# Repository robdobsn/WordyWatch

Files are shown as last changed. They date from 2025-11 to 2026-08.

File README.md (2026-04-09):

# WordyWatch

A wearable word clock watch that displays time using military time format in words. See [A Wordy Watch](https://robdobson.com/2026/04/a-wordy-watch/) for full build details. Inspired by [QlockTwo](https://www.qlocktwo.com/en-us) word clocks, WordyWatch brings this elegant time display concept to a wrist-worn device. 

## Overview

WordyWatch displays time using illuminated words instead of traditional digits. Instead of showing "11:05", it displays "eleven oh five hours". The watch uses a charlieplexed LED matrix to light up words on a custom PCB, creating a unique and readable time display.

## Military Time Format

The watch displays time in military/24-hour format with 5-minute intervals:

- `00:00` → "zero hundred hours"
- `00:05` → "zero oh five hours"  
- `11:00` → "eleven hundred hours"
- `11:05` → "eleven oh five hours"
- `23:55` → "twenty three fifty five hours"

## Key Features

- **Word-based time display** with charlieplexed LED matrix
- **Military time format** for unambiguous time reading
- **5-minute intervals** for practical readability
- **Compact wearable design** optimized for wrist-worn use
- **Custom PCB** with integrated word layout
- **ESP32-C6 based** firmware for reliable operation

## Project Structure

### 📱 **WordyWatchWebApp/**
React-based web application for designing and testing word clock layouts. This tool allows you to:
- Visualize different word arrangements and grid layouts
- Test military time display with various times
- Customize fonts and spacing
- Export layouts for use in firmware
- Experiment with new word patterns before manufacturing

Built with React 18, TypeScript, Vite, and Tailwind CSS.

See [WordyWatchWebApp/README.md](WordyWatchWebApp/README.md) for detailed usage instructions.

### 🔧 **WordyFW/**
ESP32-C6 firmware for the WordyWatch hardware. Handles:
- Real-time clock management
- LED matrix control via charlieplexing
- Power management for battery operation
- Word selection and timing logic
- User interface and button controls

### 🔌 **PCB/**
Custom PCB designs and tools for the WordyWatch hardware:

#### CharlieplexGenerator/
Python scripts for generating charlieplexed LED matrix layouts in EasyEDA format:
- `generate_charlieplex_sch.py` - Generates schematics for 12×11 LED matrices (132 LEDs)
- Automatic routing and connection generation
- Supports customizable grid spacing and positioning

See [PCB/CharlieplexGenerator/README.md](PCB/CharlieplexGenerator/README.md) for details.

### 🎨 **Design/**
Design files, documentation, and optimization experiments:
- Grid layout optimization attempts
- Word pattern analysis
- Design specifications and requirements
- Visual mockups and concepts

## Technology Stack

- **Hardware**: ESP32-C6, charlieplexed LED matrix (132 LEDs from 12 GPIO lines)
- **Firmware**: C/C++ with ESP-IDF
- **PCB Design**: EasyEDA with custom Python generators
- **Web Tools**: React 18 + TypeScript + Vite
- **LED Components**: XL-1608UWC-04 white LEDs (LCSC C965808)

## Getting Started

### For Web App Development
```bash
cd WordyWatchWebApp
npm install
npm run dev
```

### For PCB Generation
```bash
cd PCB/CharlieplexGenerator
python generate_charlieplex_sch.py SCH_TestCharlieplex1_2025-11-02.json output.json
```

### For Firmware Development
```bash
cd WordyFW
# Follow ESP-IDF build instructions
```

## How Charlieplexing Works

WordyWatch uses charlieplexing to control 132 LEDs with only 12 GPIO pins:
- With N GPIO lines, you can control N×(N-1) LEDs
- Each LED is connected between two different GPIO lines
- Only one LED (or set on the same line pair) lights at a time
- Rapid multiplexing creates the illusion of multiple LEDs being lit simultaneously

## Contributing

1. Fork the repository
2. Create a feature branch (`git checkout -b feature/amazing-feature`)
3. Commit your changes (`git commit -m 'Add amazing feature'`)
4. Push to the branch (`git push origin feature/amazing-feature`)
5. Open a Pull Request

## License

This project is open source and available under the MIT License. See [LICENSE](LICENSE) for details.

Copyright (c) 2025 Rob Dobson

## Acknowledgments

- Inspired by [QlockTwo](https://www.qlocktwo.com/en-us) word clocks
- Built for experimentation with charlieplexing and wearable displays

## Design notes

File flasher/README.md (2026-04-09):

# WordyWatch Web Flasher

A browser-based firmware flasher for the WordyWatch (ESP32-C6) using [ESP Web Tools](https://esphome.github.io/esp-web-tools/) and WebSerial.

## How it works

The flasher is a single static HTML page hosted on GitHub Pages. When a user clicks the install button, the browser connects to the watch over USB-C using the WebSerial API and flashes the firmware directly — no tools or drivers needed.

## Deployed URL

After enabling GitHub Pages, the flasher is available at:

```
https://robdobsn.github.io/WordyWatch/
```

## Build & deployment

The GitHub Actions workflow (`.github/workflows/deploy-flasher.yml`) runs automatically when a new release is published:

1. Builds the firmware inside the `espressif/idf:v5.5.2` Docker container using `idf.py -B build/WordyWatchV11 build`
2. Copies the three flash binaries (bootloader, partition table, application) into the site
3. Generates `manifest.json` with the release version tag
4. Deploys everything to GitHub Pages

The workflow can also be triggered manually from the Actions tab using `workflow_dispatch`.

## GitHub Pages setup

To enable GitHub Pages for this repo:

1. Go to **Settings → Pages** in the GitHub repository
2. Under **Build and deployment → Source**, select **GitHub Actions**

That's all — the workflow handles the rest.

## Flash layout

| Binary | Offset | Description |
|---|---|---|
| `bootloader.bin` | `0x0` | ESP32-C6 second-stage bootloader |
| `partition-table.bin` | `0x8000` | Partition table |
| `WordyWatchV11.bin` | `0x20000` | Application firmware |

## Browser support

WebSerial is required, which is supported in:

- Google Chrome (desktop)
- Microsoft Edge (desktop)

Firefox, Safari, and mobile browsers are **not supported**. The page shows a clear message to users on unsupported browsers.

## Local development

To preview the flasher page locally:

```bash
cd flasher
python3 -m http.server 8000
```

Then open `http://localhost:8000`. Note that WebSerial requires HTTPS in production, but works on `localhost` for testing.

## Files

| File | Purpose |
|---|---|
| `index.html` | Flasher page with ESP Web Tools install button |
| `firmware/manifest.json` | Template manifest (overwritten by CI with actual version) |

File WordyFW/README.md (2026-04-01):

# WordyWatch Functionality Specification

## Overview

WordyWatch is a wrist-worn word clock built on ESP32-C6, displaying the current time as illuminated English words on a 12×11 charlieplexed LED matrix. The watch sleeps between glances and wakes on wrist tilt to show the time for a few seconds before returning to deep sleep.

## Hardware Platform

| Component | Detail |
|---|---|
| MCU | ESP32-C6 (unicore, 160 MHz) |
| Display | 12×11 charlieplexed LED matrix (132 LEDs, 12 GPIO drive pins) |
| Accelerometer | LSM6DS3TR-C (I2C 0x6A) |
| RTC | RV-3028-C7 (I2C 0x52) |
| Battery sense | ADC on GPIO 2 (two-point calibrated) |
| Wake/interrupt pin | GPIO 5 (shared: accelerometer INT2 + RTC INT#) |
| Power latch | GPIO 17 (held HIGH to keep power on) |

Two hardware revisions exist (V10, V11) with different pin assignments, RTC chips, and ADC calibration. V11 is the current active revision.

## Current Functionality

### 1. Time Display (Word Clock)

The watch displays time as English words on the LED matrix using pre-generated patterns.

- **Pattern set**: 288 patterns covering 24 hours at 5-minute resolution (layout "Gracegpt8")
- **Minute granularity**: Time is floored to the nearest 5 minutes
- **Minute indicators**: Five LEDs in column x=0 at y=3..7 show minutes past the last 5-minute word time (solid), with the next indicator flashing to indicate the upcoming minute
- **Display duration**: 5 seconds (`showTimeForMs`), then the display is cleared and the watch enters deep sleep
- **Rendering**: Patterns are stored as 5×32-bit bitmasks per time entry. The WordyWatch state machine sends a `blitMask` JSON command with those words to the LED device
- **Refresh rate**: 50 Hz ISR-driven scan, with precomputed GPIO masks for each lit LED

### 2. Wake-on-Tilt

The watch wakes from deep sleep when the user raises their wrist.

- **Active mode**: Basic tilt detection using the LSM6DS3TR-C embedded functions engine (`tilt_en + func_en`)
- **Trigger**: ~35° orientation change fires INT2 (active-low, open-drain) on the shared wake pin
- **ODR**: 104 Hz accelerometer sample rate
- **Routing**: Tilt interrupt routed to INT2 via MD2_CFG register
- **Software reset**: The IMU is software-reset on every ESP boot to clear stale register state (the IMU stays powered across ESP soft resets)

### 3. Deep Sleep & Power Management

- **Sleep entry**: After displaying time for 5 seconds, the watch stops the LED panel and enters ESP32 deep sleep with EXT1 wakeup on the WAKE_INT pin (any-low trigger)
- **Power latch**: GPIO 17 is held HIGH via `gpio_hold_en` to maintain power during deep sleep
- **Deep sleep = full reset**: `esp_deep_sleep_start()` resets the CPU; on wake, the firmware restarts from `app_main()`
- **Battery monitoring**: VSENSE ADC is read every second, averaged over 100 samples. Battery voltage is computed via two-point linear calibration
- **Low battery shutdown**: When battery voltage drops below 3.45V, the power latch pin is released, cutting power
- **Power button detection**: A power button press raises the VSENSE ADC above a threshold (1550) and also pulls WAKE_INT low via a FET. Press duration is tracked with 200ms debounce. The BOOT button is GPIO9 and should only use an internal pullup after boot (strapping pin).

### 4. Battery Gauge

- **Trigger**: BOOT button (GPIO9, active-low) while the display is on; internal pullup is enabled only after boot (strapping pin)
- **Display**: Bottom row 12-LED bar gauge (left-to-right)
- **Animation**: Sweeps from 1 LED up to the target count and repeats during the display window
- **Timing**: Gauge shows for `batteryGaugeShowMs`; sweep duration `batteryGaugeSweepMs`
- **Scaling**: Battery voltage mapped between `batteryGaugeMinV` and `batteryGaugeMaxV`

### 5. RTC Timekeeping

- **Clock source**: RV-3028-C7 with 32.768 kHz CLKOUT
- **System time sync**: On every boot, the ESP32 system time is set from the RTC
- **Time read**: BCD-encoded 7-byte I2C read (seconds through year)
- **Interrupt management**: All RTC interrupt sources are disabled on init and status flags cleared to prevent spurious triggers on the shared wake pin

### 6. Time Setting

- **Serial console**: REST API endpoint `settime/YYYY-MM-DDTHH:MM:SS` sets both the RTC and system time
- **BLE Current Time Service**: Configured (read + write) but BLE is currently disabled on V11
- **Button-based time set**: Long press detection (2000ms) is configured but the time-setting state machine is not implemented

### 7. Game Mode

Two simple motion-controlled games are built in for when the display is on.

- **Enter game mode**: Long-press BOOT (≥1500 ms)
- **Exit game mode**: Long-press BOOT again, or wait for the 60s timeout
- **Cycle games**: Short-press BOOT to switch between games

**Breakout**
- Paddle on the left, bricks on the right
- Tilt the watch to move the paddle vertically
- Win by clearing the bricks; loss or win exits after a short delay

**Ball Sim**
- Sand-like grains roll under gravity
- Tilt the watch to move the grains in X/Y

### 8. LED Panel Control API

### 7. LED Panel Control API

Available via serial console REST API:

| Endpoint | Description |
|---|---|
| `leds` | LED panel status JSON |
| `leds/set?x=N&y=N&on=1` | Set individual pixel |
| `leds/clear` | Clear all LEDs |
| `leds/fill?on=1` | Fill all LEDs |
| `leds/testAllLEDs` | Sequential test of all LEDs |
| `leds/blitMask?mask=0x1,0x2` | Blit a packed mask (comma-separated 32-bit words) |
| `leds/status` | Panel status (dimensions, refresh rate, lit count, running) |

### 8. Connectivity (Currently Disabled on V11)

- **BLE**: Peripheral role with Battery, Heart Rate, Current Time, and Device Info standard services, plus a custom command/response service. Enabled on V10, disabled on V11
- **WiFi**: Disabled on both revisions
- **Serial console**: Active on UART 0 with RICSerial protocol framing

## State Machine

```
INITIAL_STATE ──→ DISPLAYING_TIME ──(5s timeout)──→ PREPARING_TO_SLEEP ──→ SLEEPING
                        ↑                                                      │
                        │                                                      │ (deep sleep resets CPU)
                        └──── WOKEN_UP ←── (EXT1 wakeup) ←── (boot) ←─────────┘

Any state ──(low battery)──→ SHUTDOWN_REQUESTED ──→ SHUTTING_DOWN
```

In practice, deep sleep resets the ESP32-C6, so every wakeup re-enters through `INITIAL_STATE`.

## Build System

- **Framework**: ESP-IDF v5.5.2 via Raft build system
- **Build command**: `raft build`
- **Flash command**: `raft r -p COM5`
- **System types**: `WordyWatchV10` and `WordyWatchV11` (separate configs and build outputs)
- **Docker**: `compose.yaml` + `Dockerfile` available for containerized builds

## Hardware Revision Differences (V10 vs V11)

| Feature | V10 | V11 |
|---|---|---|
| RTC | RV-4162-C7 (0x68) | RV-3028-C7 (0x52) |
| Wake pin | GPIO 9 | GPIO 5 |
| I2C SCL | GPIO 5 | GPIO 8 |
| BLE | Enabled | Disabled |
| Battery low voltage | 3.55V | 3.45V |
| ADC calibration | 3.2V@1002, 4.16V@1320 | 3.52V@1156, 4.32V@1413 |

---

## Planned Improvements

### 1. Button-Based Time Setting

The hardware already supports long-press detection (2000 ms threshold). A proposed time-setting flow:

1. **Enter set mode**: Long-press (≥2 s) while display is on → enter hour-setting mode
2. **Hour-setting mode**: Display flashes the current hour word. Short presses increment the hour. Long-press confirms and advances to minute-setting mode.
3. **Minute-setting mode**: Display flashes the current 5-minute word. Short presses increment by 5 minutes. Long-press confirms, writes to RTC, and returns to normal display.
4. **Timeout**: If no button press for 30 seconds in either setting mode, cancel and revert to the previous time.

Visual feedback: the word pattern should blink at ~2 Hz while in setting mode to distinguish from normal display. The PowerAndSleep class already tracks power button press duration and provides `isPowerButtonPressed()` and `getPowerButtonPressDuration()`.

---

## Technical Design

### Deep Sleep Mode

The watch spends almost all of its time in ESP32-C6 deep sleep. The lifecycle is:

```
Power on / wakeup
    │
    ├── app_main() → full firmware init (I2C, RTC, IMU, LED panel)
    ├── Read time from RTC → set system clock
    ├── Display word pattern for 5 seconds
    ├── Stop LED panel
    ├── esp_deep_sleep_start()
    │       ├── EXT1 wakeup source: GPIO 5 (WAKE_INT, any-low)
    │       ├── gpio_hold_en(GPIO 17) keeps power latch HIGH
    │       └── All RAM lost, RTC memory preserved
    │
    └── On wakeup: CPU resets, execution restarts from app_main()
```

Key details:

- **Wakeup source**: `esp_sleep_enable_ext1_wakeup(1ULL << 5, ESP_EXT1_WAKEUP_ANY_LOW)` — GPIO 5 is the shared interrupt line from the IMU (tilt) and RTC. The IMU INT2 is configured as active-low open-drain, so a tilt event pulls the line low through the external pullup.
- **Power latch**: GPIO 17 must stay HIGH during deep sleep to keep the LDO enabled. `gpio_hold_en()` freezes the pin state before entering deep sleep. On wakeup, `gpio_hold_dis()` is called (via `unisolateStrappingPins()`) to regain control.
- **Current consumption**: In deep sleep, the ESP32-C6 draws ~5 µA. The IMU (LSM6DS3TR-C at 104 Hz with embedded functions) draws ~50 µA. Total system deep sleep current is dominated by the LDO quiescent current and IMU.
- **Boot time**: Full init takes ~200–300 ms from wakeup to LED display, which is perceptually instant for a wrist-raise gesture.

### RTC Time-Setting Operation

Setting the RTC involves writing BCD-encoded time registers over I2C:

1. Convert ISO 8601 timestamp (`YYYY-MM-DDTHH:MM:SS`) to BCD fields
2. Write 7 bytes starting at register 0x00 (seconds, minutes, hours, weekday, date, month, year)
3. Call `settimeofday()` to sync the ESP32 system clock

Current entry points:
- **Serial REST API**: `settime/2025-06-15T14:30:00` — parsed by the Raft framework, calls `_rtc.setDateTime()`
- **BLE CTS** (V10 only): Write to Current Time Service characteristic triggers the same RTC write path
- **Button-based** (proposed): Would call the same `_rtc.setDateTime()` after the user selects hour and minute via button presses

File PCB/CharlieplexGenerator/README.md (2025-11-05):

# Charlieplex LED Matrix Generator for EasyEDA

The `generate_charlieplex_sch.py` script generates a charlieplexed LED matrix schematic design for EasyEDA.

## Scripts in this Directory

- **`generate_charlieplex_sch.py`** - ✅ **Use this script** - Generates EasyEDA schematics for charlieplexed LED matrices
- **`generate_charlieplex_pcb.py`** - ❌ Deprecated/non-functional - Do not use
- **`verify_pcb_labels.py`** - Helper script for PCB verification

For PCB generation information, see `PCB_GENERATOR_README.md`.

## Overview

The script creates a 12x11 charlieplexed LED matrix (132 LEDs) that can be controlled with 12 GPIO lines. Charlieplexing is a technique that allows controlling N×(N-1) LEDs using only N GPIO pins by taking advantage of the tri-state capability of microcontroller pins.

## How Charlieplexing Works

- With 12 GPIO lines, you can control 12×11 = 132 LEDs
- Each LED is connected between two different GPIO lines
- Only one LED (or one set of LEDs on the same line pair) can be lit at a time
- By rapidly multiplexing, you can create the illusion of multiple LEDs being lit simultaneously

## Usage

```bash
python generate_charlieplex_sch.py <input_file> [output_file]
```

### Parameters:
- `input_file`: Template EasyEDA JSON file (e.g., SCH_TestCharlieplex1_2025-10-31.json)
- `output_file`: Output JSON file (default: output_charlieplex.json)

### Example:
```bash
python generate_charlieplex_sch.py SCH_TestCharlieplex1_2025-10-31.json output_charlieplex.json
```

## Configuration

You can modify these constants at the top of the script to customize the layout:

- `NUM_LINES`: Number of GPIO lines (default: 12)
- `LED_SPACING_X`: Horizontal spacing between LEDs (default: 125)
- `LED_SPACING_Y`: Vertical spacing between LEDs (default: 70)
- `START_X`: Starting X position for LED matrix (default: 200)
- `START_Y`: Starting Y position for LED matrix (default: -100)
- `PORT_SPACING`: Vertical spacing between port labels (default: 70)
- `PORT_X`: X position for port labels (default: 100)
- `PORT_START_Y`: Starting Y position for port labels (default: -100)

## Generated Design

The script generates:
- **12 GPIO net ports** (GPIO0 through GPIO11) positioned at the top
- **132 LEDs** arranged in 12 vertical columns (11 LEDs per column)
- **Vertical bus lines** for each GPIO (running through all LEDs in that column)
- **Horizontal wires** connecting each LED's cathode to other GPIO columns
- **Junction points** at all connection intersections
- **Net labels** on cathode connections for easy debugging

### LED Matrix Layout

The charlieplex topology follows this structure:
- **Vertical columns**: Each GPIO has its own vertical column with (N-1) LEDs
- **Anode connections**: All LEDs in a column connect their anodes to that column's vertical bus (GPIO line)
- **Cathode connections**: Each LED's cathode connects horizontally to a different GPIO's vertical bus

For example, in the GPIO0 column:
- LED at position 0 has cathode connected to GPIO1
- LED at position 1 has cathode connected to GPIO2
- LED at position 2 has cathode connected to GPIO3
- And so on...

LED orientation:
- **All LEDs point down (Rotation 90°)**: Anode at top, cathode at bottom

## LED Component

The script uses the white LED component from LCSC:
- **Part Number**: XL-1608UWC-04
- **Package**: LED0603-RD_WHITE
- **Manufacturer**: XINGLIGHT(成兴光)
- **LCSC Part**: C965808

## Future Enhancements

Potential improvements for future versions:
- Add the charlieplexed components to an existing design (merge mode)
- Support different LED packages
- Add optional current limiting resistors
- Generate different matrix sizes
- Add visual grouping or color coding
- Export to other EDA formats

## File Structure

The generated JSON file follows the EasyEDA schematic format:
- Top-level: `editorVersion`, `docType`, `title`, `schematics`
- Schematic sheet: `dataStr` containing `head`, `canvas`, `shape`, `BBox`
- Shape array: Contains all components, wires, labels, and graphical elements

## Notes

- The design preserves the original template's frame and title block
- All components have unique IDs to prevent conflicts
- Net labels help with debugging and understanding the connections
- The horizontal bus lines simplify routing and make the design cleaner

## Importing into EasyEDA

1. Open EasyEDA (https://easyeda.com/)
2. Go to File → Open → EasyEDA Source
3. Select the generated JSON file
4. The charlieplexed LED matrix will appear in the editor

You can then:
- Add additional components (microcontroller, connectors, etc.)
- Route connections to your microcontroller
- Generate a PCB layout
- Order the PCB

## License

This script is provided as-is for educational and personal use.

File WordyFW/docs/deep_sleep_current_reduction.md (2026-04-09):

# WordyWatch Deep Sleep Current Reduction

## Baseline Measurement

- **218µA** average deep sleep current (measured 2026-04-09)

## Current Budget Estimate (Before Changes)

| Source | Est. Current | Notes |
|---|---|---|
| LSM6DS3TR-C (U14) | ~75µA | 104Hz ODR, wrist tilt enabled, embedded functions running |
| W25Q32 flash (U2) | ~25µA | Standby (not deep power-down) |
| ESP32-C6 (U1) | ~7µA | Deep sleep with RTC + EXT1 wakeup |
| XC6210 LDO (U6) | ~6-15µA | Quiescent current |
| PWR_CTRL divider (R13 470kΩ) | ~7µA | Held HIGH via gpio_hold |
| STRAP_CTRL (R27 470kΩ) | ~7µA | If pin floats high |
| MCP73831 (U4) | ~2µA | No USB connected |
| RV-3028-C7 (U15) | ~0.1µA | Negligible |
| VSENSE divider (R11+R12, 6.9MΩ) | ~0.5µA | Negligible |
| GPIO leakage (charlieplex, pull-ups) | ~50-100µA | 12 charlieplex GPIOs undefined, I2C pull-ups, internal pull-up on WAKE_INT# |

## Changes Applied

### 1. Enable flash deep power-down during sleep

- **Change:** Added `CONFIG_ESP_SLEEP_POWER_DOWN_FLASH=y` to `systypes/WordyWatchV11/sdkconfig.defaults`
- **Expected saving:** ~24µA (flash standby → deep power-down)
- **Result:** No measurable difference. Flash may already have been in a low-power state, or the ESP-IDF handles this internally for deep sleep.

### 2. IMU power-down before deep sleep

- **Change:** Added `powerDown()` method to `Accelerometer.h` — writes `0x00` to CTRL1_XL (ODR=0) and CTRL10_C (disable embedded functions). Called in `PREPARING_TO_SLEEP` state before `clearInterrupt()` in `WordyWatch.cpp`. IMU is reinitialized on wake since deep sleep resets the ESP32.
- **Expected saving:** ~72µA (75µA → ~3µA)
- **Result:** Deep sleep current dropped from 218µA to **56.6µA** — a 161.4µA saving. Larger than expected, suggesting the IMU embedded functions engine was consuming more than the datasheet typical.

## Planned Changes (Not Yet Applied)

### 3. Charlieplex GPIO hold during deep sleep

- **Change:** Added `holdPinsForSleep()` — set all 12 GPIOs to output LOW with `gpio_hold_en()`.
- **Result:** No current saving. Caused display not to turn back on after wake (gpio_hold persists across deep sleep reset and blocks reconfiguration). **Reverted.**

### 4. Remove redundant internal pull-up on WAKE_INT#

- **Change:** Set `wakeIntPinPullup` to `false` in `systypes/WordyWatchV11/SysTypes.json`. External R24 (47kΩ) already pulls up WAKE_INT#.
- **Expected saving:** minor (~1-5µA)
- **Result:** ~0.6µA saving (56.6µA → 56.0µA). Marginal but confirmed the internal pull-up was slightly redundant.

### 5. Check R18 (10kΩ) on RTC EVI pin

If U15 EVI pin has any leakage to GND, R18 at 10kΩ could waste significant current. Verify with current probe. Consider removing or increasing to 100kΩ+.

- **Expected saving:** unknown, possibly significant

## Target

Goal: reduce deep sleep current to <30µA (ESP32-C6 + LDO + RTC baseline).

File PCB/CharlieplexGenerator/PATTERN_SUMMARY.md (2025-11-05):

# Charlieplex Pattern Summary

## Pattern Analysis from Template

The template file `SCH_TestCharlieplex1_2025-10-31.json` establishes a specific charlieplex pattern with 3 ports (P1, P2, P3) and 3 LEDs per column.

### Key Measurements from Template

- **Column spacing**: 145 units (190 → 335 → 475)
- **LED spacing**: 90 units vertically (-660 → -570 → -475)
- **Starting position**: (190, -660)
- **Port label offset**: -35 units from column X position
- **Port label Y position**: -700 (40 units above first LED)

### Component Structure

#### 1. Port Labels (Top)
- **Position**: Column X - 35, Y = -700
- **Rotation**: 270° (vertical text)
- **Format**: P1, P2, P3, ... P12
- **Pattern**: One per column at the top

#### 2. LEDs
- **Position**: (Column X, Row Y)
- **Rotation**: 90° (all pointing down)
- **Designators**: LED1, LED2, LED3... LED132
- **Numbering**: Sequential across all columns

#### 3. Connections

**Anode (top pin of LED)**:
- Connected to vertical bus of its column
- Junction at anode position
- Bus runs from top port down through all LEDs

**Cathode (bottom pin of LED)**:
- Horizontal wire to another column's vertical bus
- Junction at target column
- Port label on right side (rotation 180°)

#### 4. Vertical Bus Wires
- **Path**: From port label → through all LED anodes in column
- **One per column** (12 total)
- **Connects**: Port at top to all LED anodes in that column

## Generated Matrix (12x11)

### Statistics

| Component | Count | Notes |
|---|---|---|
| LEDs | 132 | 12 columns × 11 LEDs |
| Port Labels | 144 | 12 top + 132 right side |
| Wires | 144 | 12 vertical buses + 132 horizontal cathode connections |
| Junctions | 264 | 132 anodes + 132 cathodes |
| **Total Shapes** | **685** | Including frame and all components |

### Matrix Layout

```
     P1      P2      P3      P4   ...   P11     P12
     |       |       |       |           |       |
    LED1    LED12   LED23   LED34      LED121  LED132
    →P2     →P1     →P1     →P1        →P1     →P1
     |       |       |       |           |       |
    LED2    LED13   LED24   LED35      LED122  LED133
    →P3     →P3     →P2     →P2        →P2     →P2
     |       |       |       |           |       |
    LED3    LED14   LED25   LED36      LED123  LED134
    →P4     →P4     →P4     →P3        →P3     →P3
     ...     ...     ...     ...         ...     ...
    LED11   LED22   LED33   LED44      LED131  LED143
    →P12    →P12    →P12    →P12       →P11    →P11
```

### Charlieplex Topology

**Column Structure**:
- Each column represents one GPIO port
- Each column has 11 LEDs (N-1 for N ports)
- All LEDs in a column share the same anode connection (vertical bus)

**LED Connections**:
- **Anode**: Connected to column's vertical bus (port)
- **Cathode**: Connected horizontally to a different port's bus
- Each LED connects between two different ports

**Example - Column P1**:
- LED1: Anode on P1, Cathode to P2
- LED2: Anode on P1, Cathode to P3
- LED3: Anode on P1, Cathode to P4
- ...
- LED11: Anode on P1, Cathode to P12

## File Dimensions

### Spatial Extent

- **Width**: ~1835 units (start at 190, rightmost port label at 1835)
- **Height**: ~1000 units (port at -700, last LED cathode around +300)
- **Columns**: 12 (spacing 145 units)
- **Rows per column**: 11 (spacing 90 units)

### Coordinate Ranges

- **X range**: 155 to 1855
  - 155: Leftmost port label (P1)
  - 190: First LED column
  - 1785: Last LED column (190 + 11×145)
  - 1835: Rightmost cathode port labels

- **Y range**: -700 to +310
  - -700: Top port labels
  - -660: First LED row
  - +300: Last LED row (-660 + 10×90)
  - +335: Bottom cathode port labels (+300 + 35)

## Usage

### Importing to EasyEDA

1. Open EasyEDA (https://easyeda.com/)
2. Go to **File → Open → EasyEDA Source**
3. Select `output_charlieplex_12x11_v3.json`
4. The 12×11 charlieplex matrix will appear

### Driving the Matrix

To light a specific LED:
1. Set the LED's anode port HIGH
2. Set the LED's cathode port LOW
3. Set all other ports to HIGH-Z (tri-state/input mode)
4. Only one LED (or set on same port pair) can be lit at once
5. Use multiplexing to scan through LEDs quickly

### Example Code Logic

```python
# To light LED1 (P1 anode, P2 cathode):
P1 = OUTPUT_HIGH
P2 = OUTPUT_LOW
P3-P12 = INPUT (high-Z)

# To light LED2 (P1 anode, P3 cathode):
P1 = OUTPUT_HIGH
P3 = OUTPUT_LOW
P2, P4-P12 = INPUT (high-Z)
```

## Files Generated

1. **generate_charlieplex_v3.py** - Generator script following template pattern
2. **output_charlieplex_12x11_v3.json** - Generated 12×11 matrix (280KB)
3. **PATTERN_SUMMARY.md** - This documentation

## Advantages of This Topology

1. **Clear visual structure** - Easy to trace connections
2. **Organized by port** - Each column represents one GPIO
3. **Matches reference designs** - Standard charlieplex wiring
4. **Efficient routing** - Minimal wire crossings
5. **Easy to debug** - Can trace each port's LEDs visually

## Next Steps

1. **Test in EasyEDA** - Import and verify the design
2. **Add microcontroller** - Connect to your MCU
3. **Generate PCB** - Convert schematic to PCB layout
4. **Write control code** - Implement multiplexing firmware
5. **Add current limiting** - Consider resistors if needed

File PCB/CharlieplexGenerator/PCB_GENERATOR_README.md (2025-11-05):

# Charlieplex PCB Generator

## Overview

!!! Please don't use this script as it doesn't work well and has been retired in favour of using the array layout option in EasyEDA which works well.

This script (`generate_charlieplex_pcb.py`) attempts to generate EasyEDA PCB layouts for a 12x11 charlieplexed LED matrix.

## Features
- **132 LEDs** arranged in 12 columns of 11 LEDs each
- **Template-based** LED component generation using the actual LED footprint from the template
- **264 Vias** (2 per LED) placed at both ends of each LED
  - Vias positioned along LED centerline at 135° rotation
  - Anode via: offset (-1, +1) from LED center
  - Cathode via: offset (+1, -1) from LED center
- **No traces/tracks** generated (ready for manual routing or future automation)
- **Clear, repeatable pattern** with regular spacing
- **LED Component**: LED0402-FD_YELLOW (SZYY0402Y)
- **Component Prefix**: LEDG

## Usage
```bash
python generate_charlieplex_pcb.py <template_pcb.json> <output_pcb.json>
```

Example:
```bash
python generate_charlieplex_pcb.py PCB_PCB_TestCharlieplex1_2025-11-02.json output_pcb_12x11.json
```

## PCB Layout Pattern

### LED Placement
- **Spacing**: 11.811mm horizontally, 9.8425mm vertically
- **Rotation**: 135 degrees
- **Starting Position**: (4031.811, 3425.571)

### Via Placement
Each LED has two vias placed along its centerline:

1. **Anode Via**:
   - Positioned at LED center + (-1, +1)
   - Example: LED at (3, 17) → via at (2, 18)
   - Connected to anode port net (P1-P12 depending on column)

2. **Cathode Via**:
   - Positioned at LED center + (+1, -1)
   - Example: LED at (3, 17) → via at (4, 16)
   - Connected to cathode port net (varies per LED in charlieplex pattern)

### Net Naming
- **Anode nets**: P1, P2, P3, ... P12 (one per column)
- **Cathode nets**: Distributed across all ports following charlieplex pattern

### Routing
- **No traces/tracks are generated** by this script
- Vias are ready for manual routing or automated routing tools
- Suggested routing: vertical anode buses, horizontal cathode connections

## Charlieplex Matrix Organization

For a 12-port charlieplex:
- **Column 1** (Anode = P1): Cathodes connect to P2, P3, P4, ... P12
- **Column 2** (Anode = P2): Cathodes connect to P1, P3, P4, ... P12
- **Column 3** (Anode = P3): Cathodes connect to P1, P2, P4, ... P12
- And so on...

Each column has N-1 LEDs where N is the number of ports (12).

## Configuration
You can modify these constants in the script:
- `LED_SPACING_X`: Horizontal spacing (default: 11.811)
- `LED_SPACING_Y`: Vertical spacing (default: 9.8425)
- `START_X`: Starting X coordinate (default: 4031.811)
- `START_Y`: Starting Y coordinate (default: 3425.571)
- `LED_ROTATION`: LED rotation angle (default: 135)

## Output
The script generates an EasyEDA PCB JSON file that can be imported directly into EasyEDA.

The output includes:
- **132 LED components** positioned in a grid
- **264 vias** (2 per LED) with proper net assignments
- **Board outline** automatically sized for the LED matrix
- **No traces/tracks** - ready for your routing strategy

## Notes
- The script uses the LED component from the template file, ensuring proper footprint geometry
- All unique IDs are regenerated to avoid conflicts
- Via positions are calculated based on LED centerline at 135° rotation
- Vias are properly assigned to their respective port nets (P1-P12)
- The pattern provides a clear, organized starting point for PCB routing

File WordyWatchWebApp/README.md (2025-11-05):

# Word Clock Grace

A customizable word clock web application inspired by [QlockTwo](https://www.qlocktwo.com/en-us) that displays time using military time format in words.

## Features

- **Military Time Format**: Displays time like "eleven hundred hours", "eleven oh five hours", etc.
- **Customizable Layouts**: JSON-based layout system supporting both horizontal and vertical word orientations
- **Font Customization**: Adjust font family, weight, size, letter spacing, and line height
- **Time Controls**: Manual time setting with spinners/dropdowns or automatic current time display
- **5-minute Intervals**: Time is displayed to the nearest 5 minutes
- **Responsive Design**: Built with Tailwind CSS for modern, responsive UI

## Military Time Examples

- `00:00` → "zero hundred hours"
- `00:05` → "zero oh five hours"  
- `11:00` → "eleven hundred hours"
- `11:05` → "eleven oh five hours"
- `23:55` → "twenty three fifty five hours"

## Available Layouts

1. **Military Standard**: Traditional horizontal layout with all hour and minute words
2. **Compact Vertical**: Mixed horizontal and vertical orientations in a compact grid

## Technology Stack

- **React 18** with TypeScript
- **Vite** for fast development and building
- **Tailwind CSS** for styling
- **JSON-based** layout configuration system

## Getting Started

### Prerequisites

- Node.js (version 16 or higher)
- npm or yarn

### Installation

1. Clone the repository:
   ```bash
   git clone <repository-url>
   cd WordClockGrace
   ```

2. Install dependencies:
   ```bash
   npm install
   ```

3. Start the development server:
   ```bash
   npm run dev
   ```

4. Open your browser and navigate to `http://localhost:5173`

### Building for Production

```bash
npm run build
```

The built files will be in the `dist` directory.

## Creating Custom Layouts

Layouts are defined in JSON files in the `public/layouts/` directory. Each layout file should follow this structure:

```json
{
  "name": "Layout Name",
  "description": "Layout description",
  "gridWidth": 18,
  "gridHeight": 16,
  "words": [
    {
      "word": "ZERO",
      "startRow": 0,
      "startCol": 0,
      "direction": "horizontal",
      "category": "hour"
    }
  ]
}
```

### Word Properties

- `word`: The word to display (uppercase)
- `startRow`: Starting row position (0-based)
- `startCol`: Starting column position (0-based)  
- `direction`: Either "horizontal" or "vertical"
- `category`: Word category ("hour", "minute", "military", "connector")

### Required Words

Your layout should include these words for proper military time display:

**Hours**: ZERO, ONE, TWO, THREE, FOUR, FIVE, SIX, SEVEN, EIGHT, NINE, TEN, ELEVEN, TWELVE, THIRTEEN, FOURTEEN, FIFTEEN, SIXTEEN, SEVENTEEN, EIGHTEEN, NINETEEN, TWENTY, TWENTYONE, TWENTYTWO, TWENTYTHREE

**Minutes**: OH, FIVE, TEN, FIFTEEN, TWENTY, THIRTY, FORTY, FIFTY

**Military**: HUNDRED, HOURS

## Customization Options

### Font Settings
- **Font Family**: Choose from various typefaces (monospace, sans-serif, serif)
- **Font Weight**: Adjust from thin (100) to black (900)
- **Font Size**: Scale from 8px to 72px
- **Letter Spacing**: Fine-tune character spacing
- **Line Height**: Adjust vertical spacing between rows

### Time Settings
- **Manual Time**: Use spinners and dropdowns to set specific times
- **Current Time**: Toggle to display real-time clock
- **5-minute Intervals**: All times round to nearest 5-minute mark

## Project Structure

```
src/
├── components/          # React components
│   ├── ClockDisplay.tsx    # Main clock display with letter grid
│   ├── FontControls.tsx    # Font customization controls
│   └── TimeControls.tsx    # Time input controls
├── hooks/              # Custom React hooks
│   ├── useCurrentTime.ts   # Real-time clock hook
│   └── useLayout.ts        # Layout loading and management
├── types/              # TypeScript type definitions
│   └── layout.ts           # Layout and settings interfaces
├── utils/              # Utility functions
│   └── militaryTime.ts     # Military time conversion logic
├── App.tsx             # Main application component
├── main.tsx           # Application entry point
└── index.css          # Global styles and Tailwind imports

public/
└── layouts/           # JSON layout definitions
    ├── military-standard.json
    └── compact-vertical.json
```

## Contributing

1. Fork the repository
2. Create a feature branch (`git checkout -b feature/amazing-feature`)
3. Commit your changes (`git commit -m 'Add amazing feature'`)
4. Push to the branch (`git push origin feature/amazing-feature`)
5. Open a Pull Request

## License

This project is open source and available under the [MIT License](LICENSE).

## Acknowledgments

- Inspired by [QlockTwo](https://www.qlocktwo.com/en-us) word clocks
- Built with modern web technologies for experimentation and learning

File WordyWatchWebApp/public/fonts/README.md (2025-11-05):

# Font Files for Vector DXF Export

To use vector font paths for precise laser cutting, place your font files in this directory.

## ⚠️ Copyright Notice

**All font files in this directory are subject to copyright by their respective owners and creators.** 

This project does not claim ownership of any fonts. Font files are provided for development and testing purposes only. Users are responsible for:
- Verifying they have appropriate licenses for any fonts they use
- Complying with font license terms (personal use, commercial use, redistribution, etc.)
- Obtaining proper licenses before commercial use or distribution

**When distributing this software, ensure you have the rights to include any fonts, or provide instructions for users to obtain fonts separately.**

## Supported Font Formats
- `.ttf` (TrueType)
- `.otf` (OpenType)
- `.woff2` (Web Open Font Format 2)

## Recommended Fonts for Laser Cutting
- **Arial** - Clean, simple outlines
- **Helvetica** - Similar to Arial, good for cutting
- **Courier New** - Monospace, consistent letter spacing
- **Open Sans** - Modern, readable
- **Roboto** - Google's clean font

## How to Add Fonts
1. Download your preferred font (ensure you have the license)
2. Place the `.ttf` or `.otf` file in this directory
3. Name it clearly (e.g., `arial.ttf`, `helvetica.ttf`)
4. The font will appear in the export dropdown

## Font File Names
The system looks for these specific filenames:
- `monaco.ttf` - Monaco font (matches Font Settings)
- `arial.ttf` - Arial font

## Adding Your Own Fonts
To add more fonts:
1. Place your `.ttf` or `.otf` file in this directory
2. Name it clearly (e.g., `myfont.ttf`)
3. The system will automatically detect and use it

## Fallback
If no local fonts are found, the system will try to load fonts from Google Fonts as a fallback.

## Vector vs Text Export
- **Vector Paths**: Creates closed polylines for each letter outline (recommended for laser cutting)
- **Text Entities**: Creates DXF TEXT entities (fallback if font loading fails)

For laser cutting, always use "Vector Paths" mode for the best results.

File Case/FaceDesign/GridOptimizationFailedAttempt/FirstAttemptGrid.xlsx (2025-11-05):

 |  |  |  | f | o | u | r |  | t
f |  |  | s | i | x |  |  | f | h
o |  | f | i | f | i | v | e | i | i
r |  |  |  | t |  | t |  | f | r
t | h | r | e | e | t | w | o | t | t |  | z | e | r | o
y |  | o | n | e |  | e | f | y | y
s | e | v | e | n | n | n | i | n | e |  | e | i | g | h | t
 |  |  |  |  |  | t | v
 |  |  |  |  |  | y | e |  |  |  | s | i | x
 |  |  |  |  |  |  |  |  |  |  |  | n | i | n | e
 |  |  |  |  |  |  |  |  |  |  | t | h | i | r
 |  |  |  |  |  |  |  |  |  |  | f | i | f |  |  | t | e | e | n | (to the right or below)
 |  |  |  |  |  |  |  |  |  |  | t | w | e | n | t | y | (to the left of 1234)
 |  |  | h | t | f | t | t | f | f | f
 |  |  | u | e | i | w | h | o | i | i
 |  |  | n | n | f | e | i | r | f | v
 |  |  | d |  | t | n | r | t | t | e
 |  |  | r |  | e | t | t | y | y
 |  |  | e |  | e | y | y
 |  |  | d |  | n

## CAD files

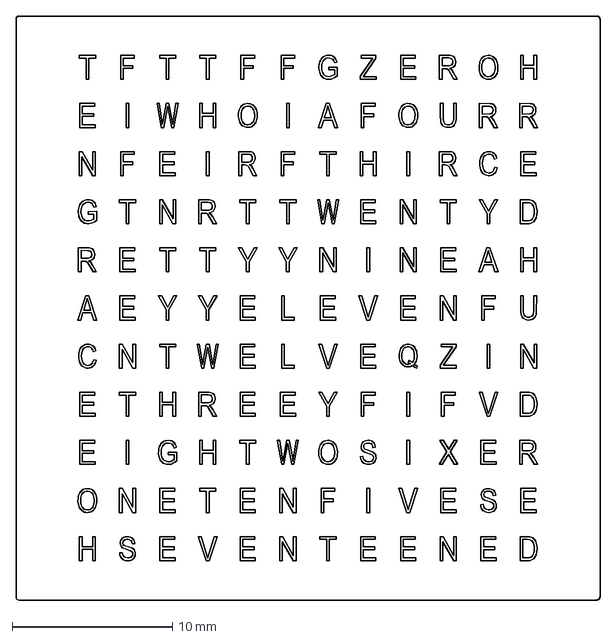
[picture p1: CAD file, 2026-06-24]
Case/FacePrint/Watch Face Printable.dxf
36.4 x 36.4 mm

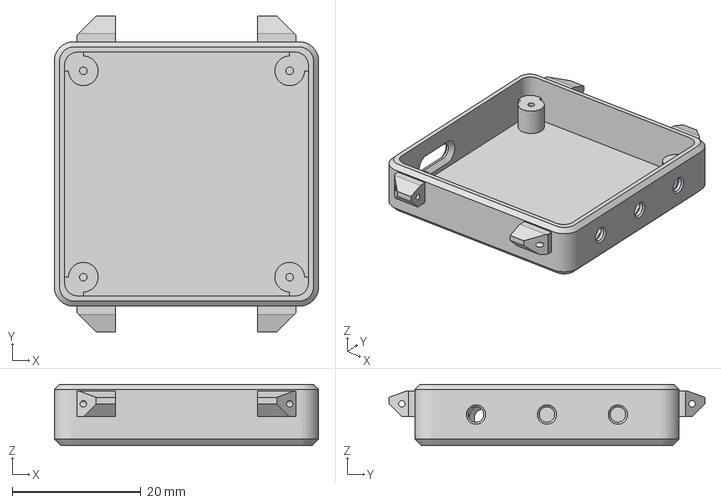
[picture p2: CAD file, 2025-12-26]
Case/Outputs3D/Wordy Watch Case.3mf
41.0 x 49.0 x 9.47 mm

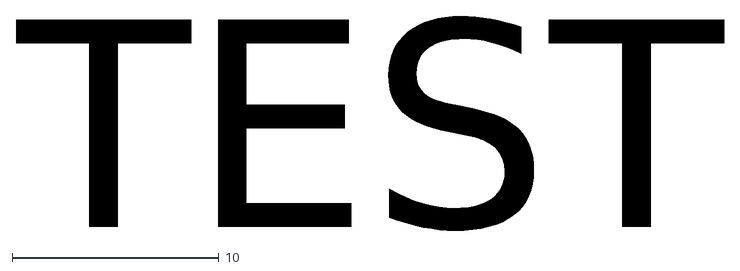
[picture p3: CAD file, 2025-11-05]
WordyWatchWebApp/tools/validate-dxf/test.dxf
TEST

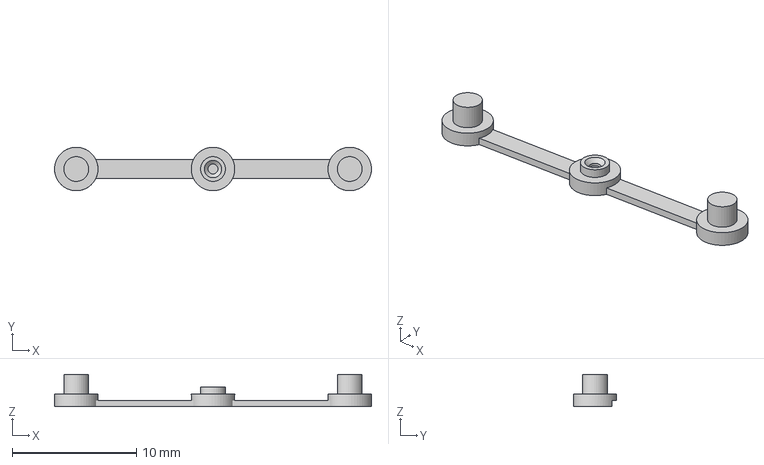
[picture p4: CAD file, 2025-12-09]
Case/Outputs3D/Wordy Watch Button.3mf
25.5 x 3.50 x 2.60 mm

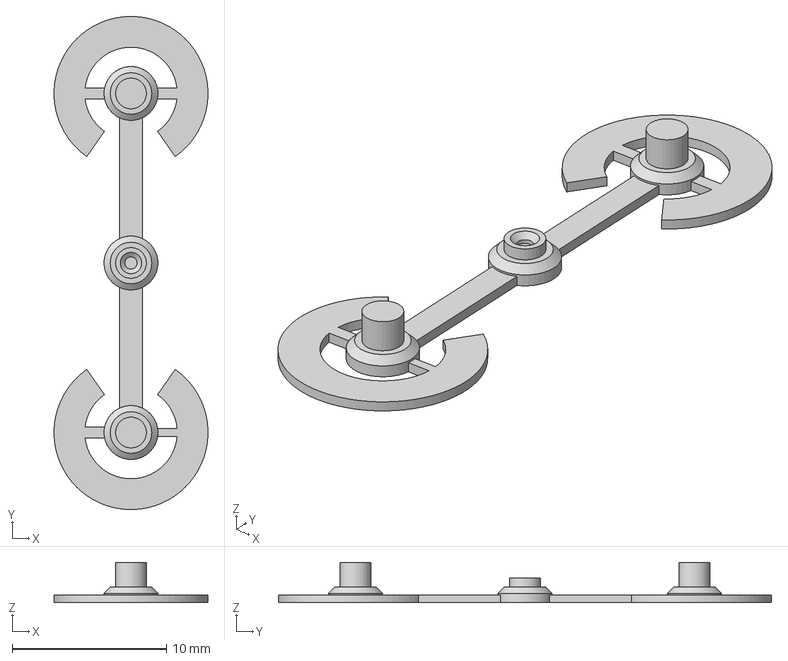
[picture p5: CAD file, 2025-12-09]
Case/Outputs3D/Wordy Watch Button with Support.3mf
9.99 x 32.0 x 2.60 mm

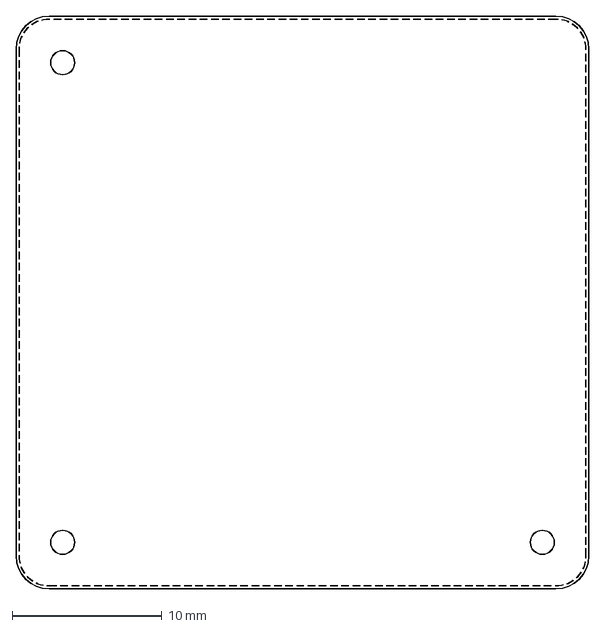
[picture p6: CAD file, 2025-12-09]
Case/Outputs3D/Front Sheet Laser Cut.dxf
38.2 x 38.2 mm

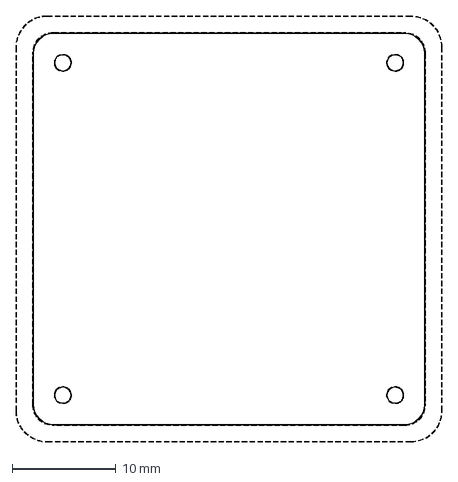
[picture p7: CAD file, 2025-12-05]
Case/Outputs3D/Front Face.dxf
41.0 x 41.0 mm

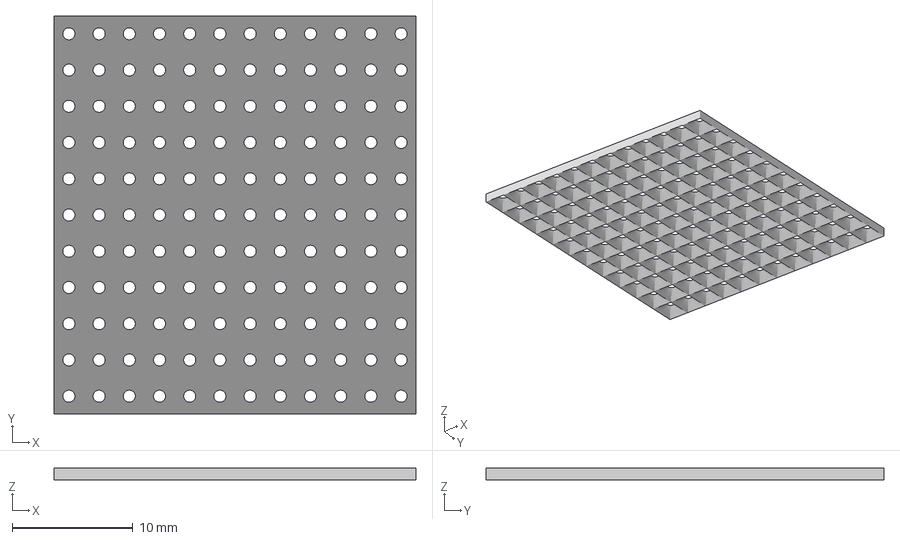
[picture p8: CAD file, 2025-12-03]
Case/Outputs3D/LED Diffuser Blocking.3mf
29.9 x 33.0 x 1.00 mm

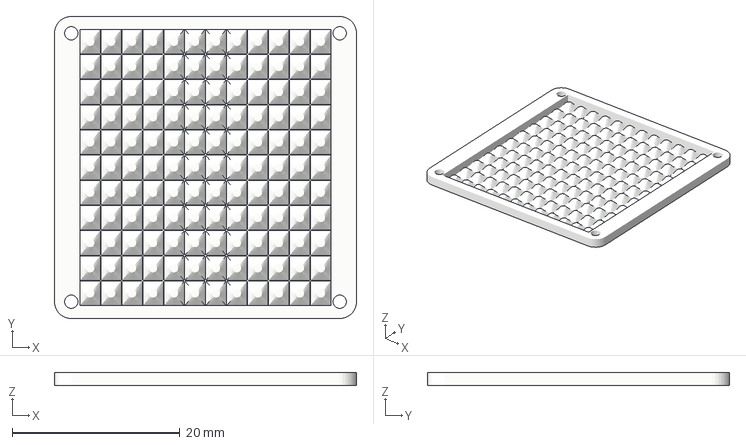
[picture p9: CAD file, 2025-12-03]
Case/Outputs3D/LED Diffuser Pyramids.3mf
36.0 x 36.0 x 1.50 mm

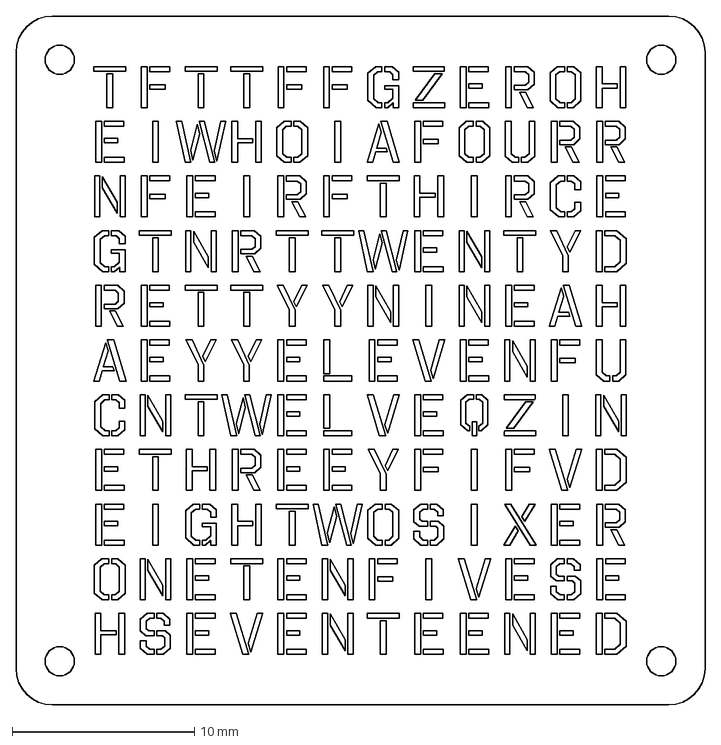
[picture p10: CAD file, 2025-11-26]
Case/Outputs3D/Cutting Outline.dxf
37.8 x 37.8 mm

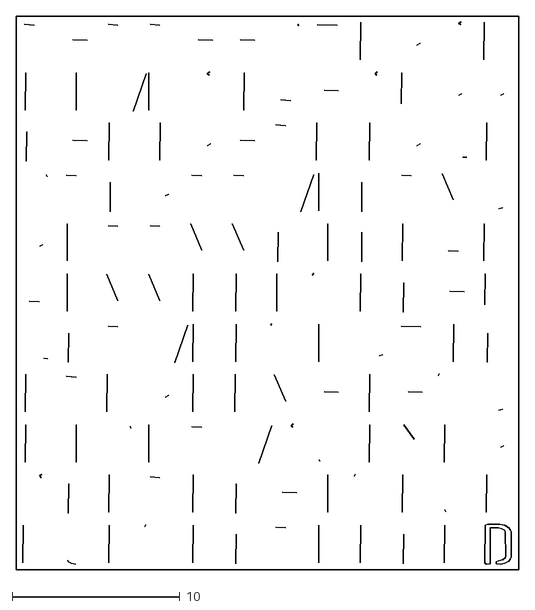
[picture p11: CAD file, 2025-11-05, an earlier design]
PCB/V1.0/wordclock-grid.dxf
30.0 x 33.0

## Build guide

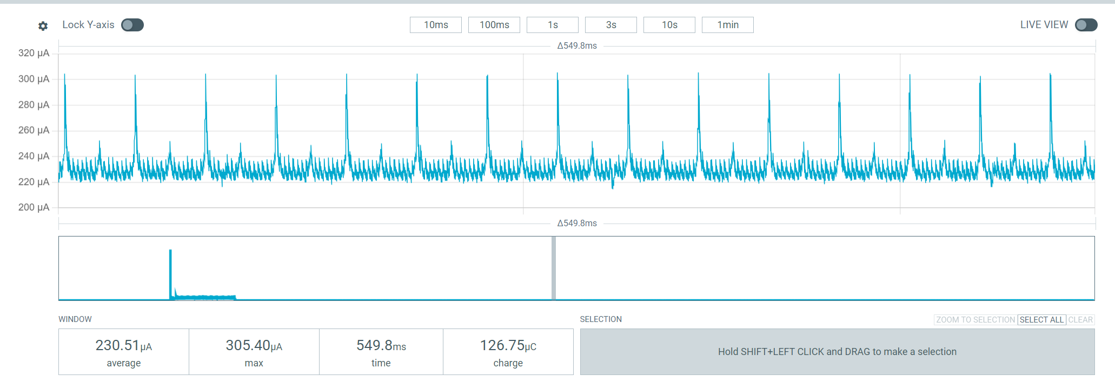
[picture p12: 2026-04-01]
WordyFW/docs/2026-04-01 091548 V1.1 power usage on deep sleep.png

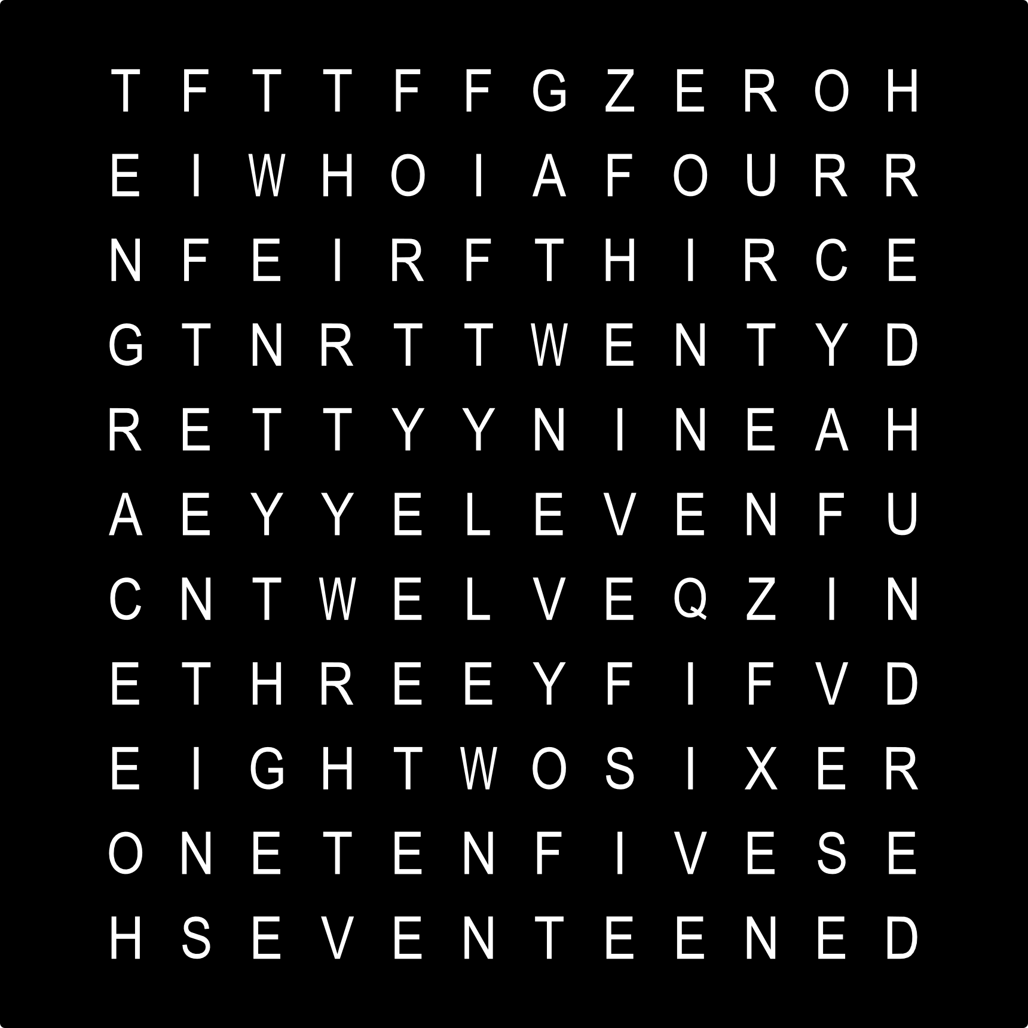
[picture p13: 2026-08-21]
Case/FacePrint/Watch Face Print.png

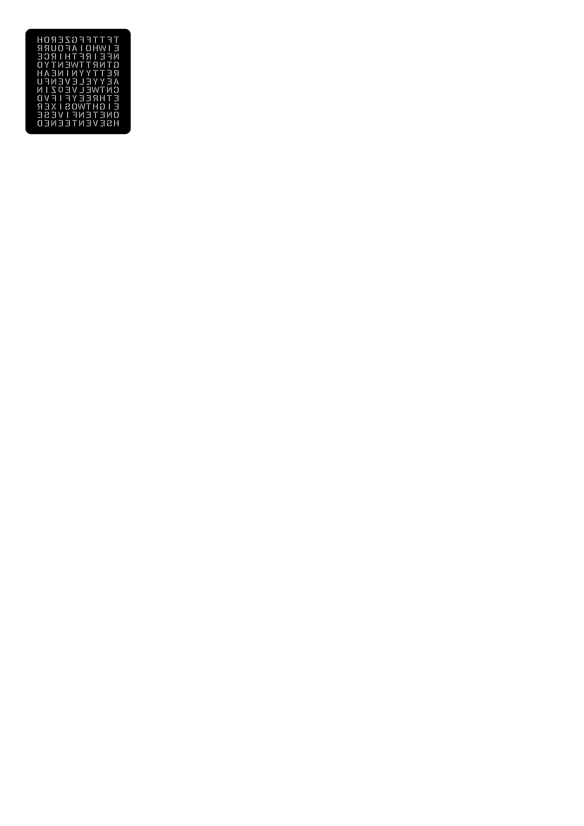
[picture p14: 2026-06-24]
Case/FacePrint/Face Print Reversed No Holes.png

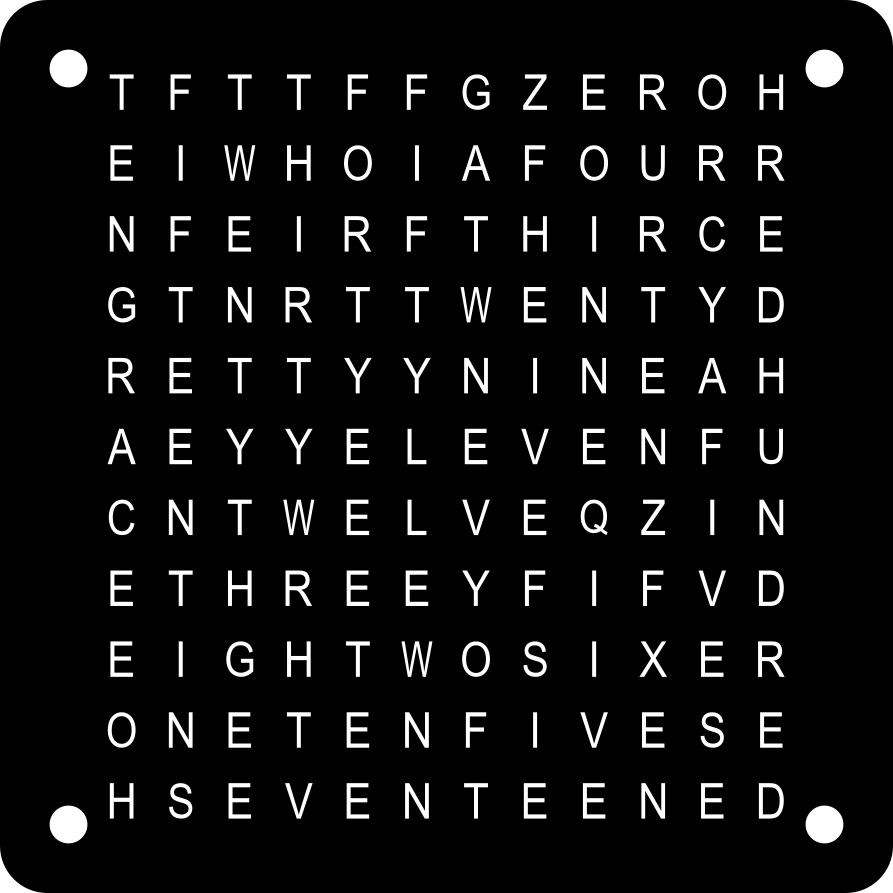
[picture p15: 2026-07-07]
Case/FacePrint/g136.png

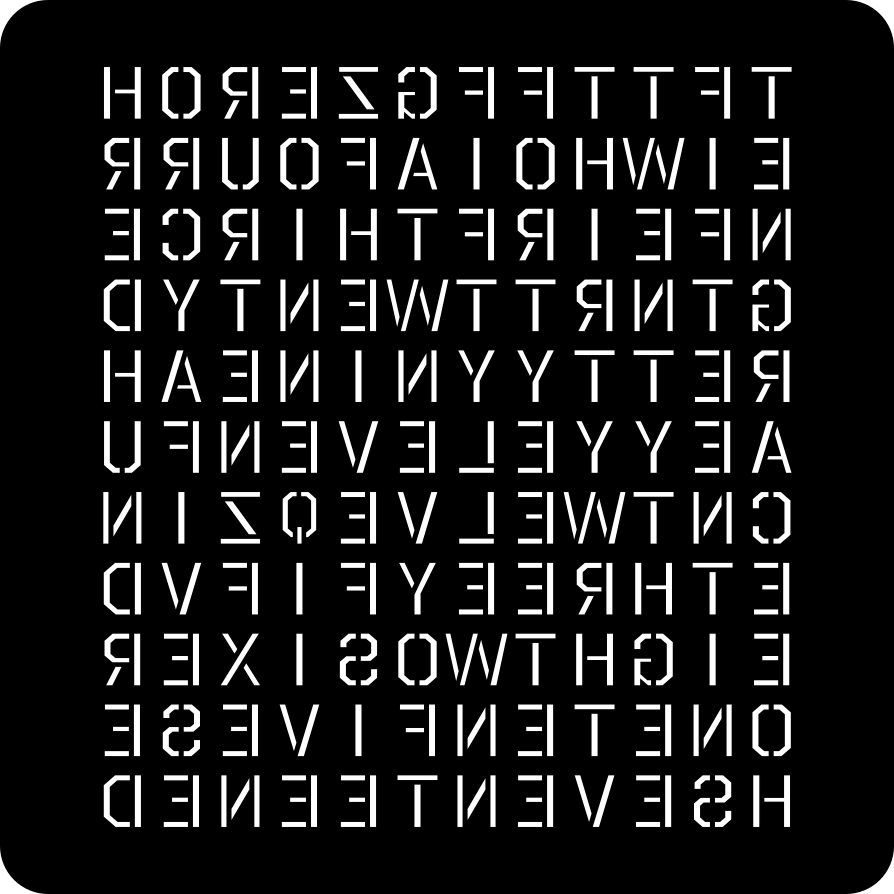
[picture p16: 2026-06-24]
Case/FacePrint/WordyWatch Face Reversed No Holes Export.png

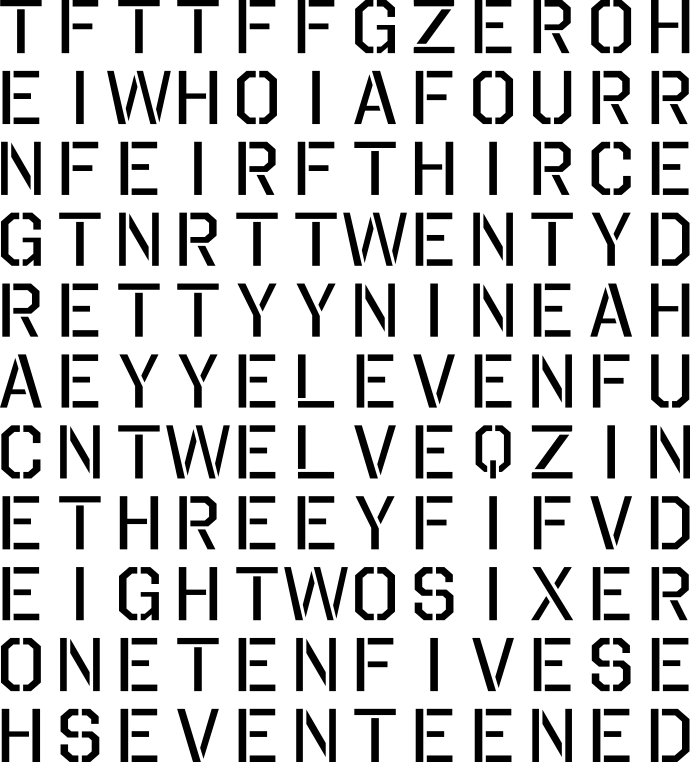
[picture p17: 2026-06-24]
Case/FacePrint/WordyWatch Face Inverted.png

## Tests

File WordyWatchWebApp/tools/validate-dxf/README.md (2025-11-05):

# DXF Validation Tool

A Python tool for validating DXF files and providing detailed error reporting to help debug DXF generation issues.

## Installation

1. Install Python 3.7 or higher
2. Install dependencies:
   ```bash
   pip install -r requirements.txt
   ```

## Usage

### Basic validation:
```bash
python validate_dxf.py file.dxf
```

### Verbose output:
```bash
python validate_dxf.py -v file.dxf
```

### Save detailed report:
```bash
python validate_dxf.py --output report.txt file.dxf
```

## What it validates

- **File structure**: Checks if file exists and is readable
- **DXF format**: Validates DXF structure and version
- **Sections**: Verifies presence of required sections (HEADER, TABLES, BLOCKS, ENTITIES, OBJECTS)
- **Tables**: Checks for standard tables (layers, styles, views, etc.)
- **Entities**: Validates TEXT, LINE, and LWPOLYLINE entities
- **Handles**: Ensures all entity handles are unique and valid
- **Geometry**: Validates entity properties and geometry

## Output

The tool provides:
- ✅ Success indicators for valid components
- ❌ Error messages for critical issues
- ⚠️ Warning messages for potential problems
- Detailed entity counts and structure analysis
- Optional detailed report file

## Common DXF Issues

- **Missing sections**: DXF files need HEADER, TABLES, BLOCKS, ENTITIES, and OBJECTS sections
- **Invalid handles**: Each entity must have a unique, valid handle
- **Malformed entities**: TEXT entities need proper text content and positioning
- **Unclosed polylines**: LWPOLYLINE entities marked as closed must actually be closed
- **Missing tables**: Some CAD software requires specific tables to be present

## Examples

### Valid DXF:
```
✓ Successfully loaded DXF version: R2013
✓ No errors found
✓ No warnings found
```

### Invalid DXF:
```
✗ DXF Structure Error: Missing HEADER section
❌ ERRORS (1):
  1. DXF Structure Error: Missing HEADER section
```

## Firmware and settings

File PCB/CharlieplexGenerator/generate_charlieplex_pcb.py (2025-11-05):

#!/usr/bin/env python3
"""
Generate EasyEDA PCB JSON for a charlieplexed LED matrix
Based on the provided template PCB design
"""

import json
import sys
import hashlib
import copy
import re
from typing import Dict, Tuple, List

# PCB Layout Configuration
# EasyEDA PCB units: 1 unit = 0.254mm (10 mils)
# To convert mm to PCB units: mm / 0.254
MM_TO_PCB_UNITS = 1.0 / 0.254  # Approximately 3.937

LED_SPACING_X_MM = 2.5          # Horizontal spacing in millimeters
LED_SPACING_Y_MM = 3.0          # Vertical spacing in millimeters
LED_SPACING_X = LED_SPACING_X_MM * MM_TO_PCB_UNITS  # Convert to PCB units
LED_SPACING_Y = LED_SPACING_Y_MM * MM_TO_PCB_UNITS  # Convert to PCB units

START_X = 4031.811      # Starting X position (PCB units)
START_Y = 3425.571      # Starting Y position (PCB units)
LED_ROTATION = 135      # LED rotation angle

def generate_unique_id(prefix: str, seed: int) -> str:
    """Generate a unique ID similar to EasyEDA format"""
    hash_input = f"{prefix}_{seed}".encode('utf-8')
    hash_val = hashlib.md5(hash_input).hexdigest()
    return f"gge{hash_val[:15]}"

def extract_led_template(template: Dict) -> str:
    """Extract the first LED component from the template to use as a base"""
    for shape in template['shape']:
        if isinstance(shape, str) and shape.startswith('LIB~') and 'LED0402-FD_YELLOW' in shape:
            return shape
    return None

def extract_leds_from_schematic(schematic_file: str) -> List[Dict]:
    """Extract LED information from the schematic JSON
    Returns list of dicts with: led_num, anode_port, cathode_port"""
    try:
        with open(schematic_file, 'r', encoding='utf-8') as f:
            schematic = json.load(f)
        
        leds = []
        shapes = schematic['schematics'][0]['dataStr']['shape']
        
        for shape in shapes:
            if isinstance(shape, str) and 'LIB~' in shape and 'LED0402-FD_YELLOW' in shape:
                # Extract LED number from the component label (Z1, Z2, etc.)
                # Look for the comment field with Z#
                if '~Z' in shape:
                    # Find the Z# label
                    parts = shape.split('~')
                    led_label = None
                    for part in parts:
                        if part.startswith('Z') and part[1:].isdigit():
                            led_label = part
                            break
                    
                    if led_label:
                        led_num = int(led_label[1:])
                        # Store LED info - we'll determine ports from matrix pattern
                        leds.append({'led_num': led_num})
        
        # Sort by LED number
        leds.sort(key=lambda x: x['led_num'])
        
        # Now assign anode and cathode ports based on charlieplex pattern
        num_ports = 12
        for led_info in leds:
            led_num = led_info['led_num']
            # Calculate which column this LED is in (0-indexed)
            col_idx = (led_num - 1) // (num_ports - 1)
            anode_port = col_idx
            
            # Calculate position within column
            led_in_col = (led_num - 1) % (num_ports - 1)
            
            # Cathode port sequence: all ports except the anode port
            cathode_sequence = [p for p in range(num_ports) if p != anode_port]
            cathode_port = cathode_sequence[led_in_col]
            
            led_info['anode_port'] = anode_port + 1  # 1-indexed (P1, P2, etc.)
            led_info['cathode_port'] = cathode_port + 1  # 1-indexed
        
        return leds
    except Exception as e:
        print(f"Warning: Could not extract LEDs from schematic: {e}")
        return []

def create_led_component(x: float, y: float, led_num: int, anode_port: int, cathode_port: int, template_led: str, template_x: float, template_y: float) -> str:
    """Create an LED component at position (x, y) by modifying the template
    This properly offsets ALL coordinates within the LED component"""
    if not template_led:
        # Fallback simplified version
        uid = generate_unique_id('led', led_num * 100)
        return f"LIB~{x}~{y}~package`LED0402-FD_YELLOW`~{LED_ROTATION}~~{uid}~2~~0~~yes~~"
    
    # Calculate offset from template position
    offset_x = x - template_x
    offset_y = y - template_y
    
    # Replace component prefix and label
    led_str = template_led.replace('spicePre`U`', 'spicePre`Z`')
    led_str = led_str.replace('~U1~', f'~Z{led_num}~')
    led_str = led_str.replace('~U2~', f'~Z{led_num}~')
    
    # Update PAD net assignments
    # PAD format: PAD~RECT~x~y~...~net~pad_num~...
    # Need to replace P1 and P2 with the correct anode and cathode port nets
    led_str = re.sub(r'(PAD~[^~]+~[^~]+~[^~]+~[^~]+~[^~]+~[^~]+~)P2(~2~)', 
                     rf'\1P{anode_port}\2', led_str)
    led_str = re.sub(r'(PAD~[^~]+~[^~]+~[^~]+~[^~]+~[^~]+~[^~]+~)P1(~1~)', 
                     rf'\1P{cathode_port}\2', led_str)
    
    # Generate new unique IDs
    id_pattern = r'gge[a-f0-9]+'
    counter = 0
    def replace_id(match):
        nonlocal counter
        counter += 1
        return generate_unique_id(f'led{led_num}', counter)
    led_str = re.sub(id_pattern, replace_id, led_str)
    
    # Now offset all numeric coordinates in the string
    # Pattern to find floating point numbers (coordinates)
    def offset_coordinate(match, is_x_coord):
        """Offset a coordinate value"""
        value = float(match.group(0))
        # Only offset if the value is near the template position (within reasonable range)
        # This avoids offsetting things like rotation angles, sizes, etc.
        if is_x_coord and abs(value - template_x) < 100:
            return str(value + offset_x)
        elif not is_x_coord and abs(value - template_y) < 100:
            return str(value + offset_y)
        return match.group(0)
    
    # Split by ~ to process each part
    parts = led_str.split('~')
    # Update the main position (parts 1 and 2)
    if len(parts) > 2:
        parts[1] = str(x)
        parts[2] = str(y)
    
    # Rejoin and process internal coordinates
    led_str = '~'.join(parts)
    
    # Find all coordinate pairs in the format "number number" (space separated)
    # This is used for things like "M 4031.811 3425.571 L ..."
    coord_pattern = r'(\d+\.?\d*)\s+(\d+\.?\d*)'
    def offset_coord_pair(match):
        x_val = float(match.group(1))
        y_val = float(match.group(2))
        # Only offset if near template position
        if abs(x_val - template_x) < 100 and abs(y_val - template_y) < 100:
            return f'{x_val + offset_x} {y_val + offset_y}'
        return match.group(0)
    
    led_str = re.sub(coord_pattern, offset_coord_pair, led_str)
    
    return led_str

def generate_charlieplex_pcb(template: Dict, led_info_list: List[Dict], num_ports: int = 12) -> Dict:
    """
    Generate charlieplexed LED matrix PCB layout
    - LEDs arranged in columns (one column per anode port)
    - No vias or traces generated
    """
    output = copy.deepcopy(template)
    
    # Extract LED template and its position
    template_led = extract_led_template(template)
    if not template_led:
        print("Warning: Could not find LED template in PCB file")
        return output
    
    # Extract template LED position
    template_parts = template_led.split('~')
    template_x = float(template_parts[1])
    template_y = float(template_parts[2])
    print(f"  - Template LED at ({template_x}, {template_y})")
    
    # Clear existing shapes except board outline
    shapes = output['shape']
    board_outline = [s for s in shapes if 'BoardOutLine' in str(s)]
    shapes.clear()
    if board_outline:
        shapes.extend(board_outline)
    
    # Calculate PCB dimensions
    pcb_width = (num_ports - 1) * LED_SPACING_X + 20  # Extra margin
    pcb_height = (num_ports - 1) * LED_SPACING_Y + 20  # Extra margin
    
    # Create board outline
    outline_x = START_X - 10
    outline_y = START_Y - 10
    outline = f"TRACK~1~10~~{outline_x} {outline_y} {outline_x + pcb_width} {outline_y} {outline_x + pcb_width} {outline_y + pcb_height} {outline_x} {outline_y + pcb_height} {outline_x} {outline_y}~{generate_unique_id('outline', 0)}~0"
    shapes.append(outline)
    
    # Create LEDs using information from schematic
    for led_info in led_info_list:
        led_num = led_info['led_num']
        anode_port = led_info['anode_port']  # 1-indexed (P1, P2, etc.)
        cathode_port = led_info['cathode_port']  # 1-indexed
        
        # Calculate position based on LED number
        # LEDs are arranged in columns by anode port
        col_idx = anode_port - 1  # 0-indexed for calculation
        led_in_col = (led_num - 1) % (num_ports - 1)
        
        col_x = START_X + (col_idx * LED_SPACING_X)
        led_y = START_Y + (led_in_col * LED_SPACING_Y)
        
        # Create LED component with proper coordinate offsetting
        led = create_led_component(col_x, led_y, led_num, anode_port, cathode_port, 
                                  template_led, template_x, template_y)
        shapes.append(led)
    
    # Update BBox
    output['BBox'] = {
        "x": outline_x,
        "y": outline_y,
        "width": pcb_width,
        "height": pcb_height
    }
    
    return output

def main():
    if len(sys.argv) != 4:
        print("Usage: python generate_charlieplex_pcb.py <schematic.json> <template_pcb.json> <output_pcb.json>")
        print("  schematic.json: The generated schematic with LED definitions")
        print("  template_pcb.json: PCB template with LED footprint")
        print("  output_pcb.json: Output PCB file")
        sys.exit(1)
    
    schematic_file = sys.argv[1]
    template_file = sys.argv[2]
    output_file = sys.argv[3]
    
    print(f"Loading schematic from: {schematic_file}")
    led_info_list = extract_leds_from_schematic(schematic_file)
    if not led_info_list:
        print("ERROR: No LEDs found in schematic!")
        sys.exit(1)
    print(f"  - Found {len(led_info_list)} LEDs in schematic")
    
    print(f"Loading PCB template from: {template_file}")
    with open(template_file, 'r', encoding='utf-8') as f:
        template = json.load(f)
    
    print("Generating 12x11 charlieplexed LED matrix PCB...")
    print(f"  - LED spacing: {LED_SPACING_X_MM}mm x {LED_SPACING_Y_MM}mm ({LED_SPACING_X:.3f} x {LED_SPACING_Y:.3f} PCB units)")
    print(f"  - Starting position: ({START_X}, {START_Y})")
    print(f"  - LED rotation: {LED_ROTATION} degrees")
    print(f"  - Component prefix: Z")
    print(f"  - No vias or traces generated")
    print(f"  - Unit conversion: 1mm = {MM_TO_PCB_UNITS:.3f} PCB units")
    
    pcb = generate_charlieplex_pcb(template, led_info_list, num_ports=12)
    
    print(f"Writing output to: {output_file}")
    with open(output_file, 'w', encoding='utf-8') as f:
        json.dump(pcb, f, ensure_ascii=False, indent=2)
    
    print(f"Done! Generated {len(led_info_list)} LEDs")

if __name__ == '__main__':
    main()

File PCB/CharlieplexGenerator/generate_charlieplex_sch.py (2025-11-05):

#!/usr/bin/env python3
"""
Generate a 12x11 charlieplexed LED matrix schematic for EasyEDA
Following the exact pattern from the template file
"""

import json
import copy
from typing import List, Dict, Tuple

# Configuration - following the pattern from template
NUM_PORTS = 12       # Number of GPIO ports
COL_SPACING = 145    # Horizontal spacing between columns (190 to 335 to 475)
LED_SPACING_Y = 90   # Vertical spacing between LEDs
START_X = 190        # Starting X position for first column
START_Y = -660       # Starting Y position for first LED
PORT_TOP_OFFSET_X = -35  # Port label X offset from column (-35 from 190 = 155)
PORT_TOP_Y = -700    # Y position for top port labels
PORT_RIGHT_OFFSET_Y = 35  # Y offset for right-side port labels from LED cathode

def load_template(filename: str) -> Dict:
    """Load the template EasyEDA JSON file"""
    with open(filename, 'r', encoding='utf-8') as f:
        return json.load(f)

def generate_unique_id(prefix: str, index: int) -> str:
    """Generate a unique ID for components"""
    import hashlib
    import random
    # Generate a unique hash-like ID similar to EasyEDA format
    unique_str = f"{prefix}{index}{random.randint(0, 99999)}"
    hash_val = hashlib.md5(unique_str.encode()).hexdigest()[:16]
    return f"gge{hash_val}"

def create_led(x: float, y: float, led_num: int) -> str:
    """Create an LED component (rotation 90 - anode up, cathode down)"""
    uid = generate_unique_id('led', led_num)
    uid1 = generate_unique_id('led', led_num + 1)
    uid2 = generate_unique_id('led', led_num + 2)
    uid3 = generate_unique_id('led', led_num + 3)
    uid4 = generate_unique_id('led', led_num + 4)
    uid5 = generate_unique_id('led', led_num + 5)
    uid6 = generate_unique_id('led', led_num + 6)
    uid7 = generate_unique_id('led', led_num + 7)
    uid8 = generate_unique_id('led', led_num + 8)
    uid9 = generate_unique_id('led', led_num + 9)
    uid10 = generate_unique_id('led', led_num + 10)
    uid11 = generate_unique_id('led', led_num + 11)
    uid12 = generate_unique_id('led', led_num + 12)
    
    # Rotation 270: Anode (pin 1) at top (y-20), Cathode (pin 2) at bottom (y+20)
    led_str = f"LIB~{x}~{y}~package`LED0402-FD_YELLOW`Contributor`lcsc`Supplier`LCSC`Supplier Part`C434450`Manufacturer`yongyu(永裕光电)`Manufacturer Part`SZYY0402Y`JLCPCB Part Class`Extended Part`spicePre`Z`spiceSymbolName`SZYY0402Y_C434450`~270~0~{uid}~15ae3cf5adbd445ca10066bc58786d84~b106fb803393431a9aa5596d75152a94~0~~yes~yes~4a184aa6289b47e29467d92858c05a4b~1706500802~387e8451b7aa40ab87922675a70d709c#@$T~N~{x+19}~{y+12.33}~0~#000080~Arial~~~~~comment~SZYY0402Y_C434450~1~start~{uid1}~0~#@$T~P~{x+19}~{y+3.26}~0~#000080~Arial~~~~~comment~Z{led_num}~1~start~{uid2}~0~#@$PT~M {x+13} {y+16} L {x+11} {y+12} L {x+9} {y+14} Z ~#880000~1~0~none~{uid3}~0~#@$PT~M {x+17} {y+12} L {x+15} {y+8} L {x+13} {y+10} Z ~#880000~1~0~none~{uid4}~0~#@$PL~{x+6} {y+9} {x+10} {y+13}~#880000~1~0~#880000~{uid5}~0#@$PL~{x+10} {y+5} {x+14} {y+9}~#880000~1~0~#880000~{uid6}~0#@$PL~{x} {y+5} {x} {y+10}~#880000~1~0~none~{uid7}~0#@$PL~{x} {y-10} {x} {y-5}~#880000~1~0~none~{uid8}~0#@$PL~{x+7} {y+5} {x-7} {y+5}~#880000~1~0~none~{uid9}~0#@$PT~M {x+7} {y-5} L {x} {y+5} L {x-7} {y-5} Z ~#880000~1~0~#FFFF00~{uid10}~0~#@$P~show~0~2~{x}~{y+20}~270~{uid11}~0^^{x}~{y+20}^^M {x} {y+20} v -10~#880000^^0~{x+3}~{y+7}~270~K~start~~~#0000FF^^0~{x-1}~{y+13}~270~2~end~~~#0000FF^^0~{x}~{y+13}^^0~M {x+3} {y+10} L {x} {y+7} L {x-3} {y+10}#@$P~show~0~1~{x}~{y-20}~90~{uid12}~0^^{x}~{y-20}^^M {x} {y-20} v 10~#880000^^0~{x+3}~{y-7}~270~A~end~~~#0000FF^^0~{x-1}~{y-13}~270~1~start~~~#0000FF^^0~{x}~{y-13}^^0~M {x-3} {y-10} L {x} {y-7} L {x+3} {y-10}"
    
    # Return LED string and pin positions
    # With rotation 270: Anode (pin 1) at top (y-20), Cathode (pin 2) at bottom (y+20)
    anode_pos = (x, y - 20)  # Pin 1 - top (anode)
    cathode_pos = (x, y + 20)  # Pin 2 - bottom (cathode)
    return led_str, anode_pos, cathode_pos

def create_port_label_top(x: float, y: float, port_name: str, index: int) -> str:
    """Create a port label at top (rotation 270)"""
    uid1 = generate_unique_id('port', index * 10)
    uid2 = generate_unique_id('port', index * 10 + 1)
    uid3 = generate_unique_id('port', index * 10 + 2)
    
    port_str = f"F~part_netLabel_netPort~{x}~{y}~270~{uid1}~~0^^{x}~{y}^^{port_name}~#0000FF~{x+3.6}~{y-22}~270~~1~Times New Roman~8pt~{uid2}^^PL~{x} {y} {x-5} {y-5} {x-5} {y-20} {x+5} {y-20} {x+5} {y-5} {x} {y}~#0000FF~1~0~transparent~{uid3}~0"
    return port_str

def create_port_label_right(x: float, y: float, port_name: str, index: int) -> str:
    """Create a port label on right side (rotation 180)"""
    uid1 = generate_unique_id('port', index * 10 + 3)
    uid2 = generate_unique_id('port', index * 10 + 4)
    uid3 = generate_unique_id('port', index * 10 + 5)
    
    port_str = f"F~part_netLabel_netPort~{x}~{y}~180~{uid1}~~0^^{x}~{y}^^{port_name}~#0000FF~{x+22}~{y+3.6}~0~~1~Times New Roman~8pt~{uid2}^^PL~{x} {y} {x+5} {y+5} {x+20} {y+5} {x+20} {y-5} {x+5} {y-5} {x} {y}~#0000FF~1~0~transparent~{uid3}~0"
    return port_str

def create_wire(x1: float, y1: float, x2: float, y2: float, *extra_points, index: int = 0) -> str:
    """Create a wire (can have multiple segments)"""
    uid = generate_unique_id('wire', index)
    points = [(x1, y1), (x2, y2)]
    if extra_points:
        # Insert extra points between first and last
        points = [(x1, y1)] + list(extra_points) + [(x2, y2)]
    
    coords = ' '.join([f"{x} {y}" for x, y in points])
    wire_str = f"W~{coords}~#008800~1~0~none~{uid}~0"
    return wire_str

def create_junction(x: float, y: float, index: int) -> str:
    """Create a junction point"""
    uid = generate_unique_id('junc', index)
    junc_str = f"J~{x}~{y}~2.5~#CC0000~{uid}~0"
    return junc_str
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

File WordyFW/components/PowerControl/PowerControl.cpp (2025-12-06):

/////////////////////////////////////////////////////////////////////////////////////////////////////////////////
//
// Power control
//
// Rob Dobson 2023
//
/////////////////////////////////////////////////////////////////////////////////////////////////////////////////

#include "PowerControl.h"
#include "RaftJsonIF.h"
#include "ConfigPinMap.h"
#include "RaftUtils.h"
#include "esp_sleep.h"

#define DEBUG_USER_BUTTON_PRESS
#define DEBUG_POWER_CONTROL

namespace
{
    static constexpr const char* MODULE_PREFIX = "PowerControl";
}

/// @brief Constructor for PowerControl
/// @param pClassName Class name
/// @param pDevConfigJson Device configuration JSON
PowerControl::PowerControl(const char* pClassName, const char* pDevConfigJson)
    : RaftDevice(pClassName, pDevConfigJson)
{
}

/// @brief Destructor for PowerControl
PowerControl::~PowerControl()
{
}

/// @brief Setup the PowerControl device
void PowerControl::setup()
{
    _isConfigured = applyConfiguration();
    if (!_isConfigured)
    {
        LOG_E(MODULE_PREFIX, "setup configuration failed");
    }
}

/// @brief Main loop for the PowerControl device (called frequently)
void PowerControl::loop()
{
    // Update VSENSE average
    if (_vsensePin < 0)
        return;

    // Get VSENSE value
    uint32_t vsenseVal = analogRead(_vsensePin);

    // The pushbutton is wired to VSENSE so if it is pressed the VSENSE pin
    // will go above a threshold
    if (vsenseVal > _vsenseButtonLevel)
    {
        // Note time press started
        if (!_buttonPressed)
            _buttonPressDownTimeMs = millis();

        // Pressed
        _buttonPressed = true;
        _buttonPressChangeTimeMs = millis();

        // Check if button press is over the off time threshold
        if (Raft::timeElapsed(millis(), _buttonPressDownTimeMs) > _buttonOffTimeMs)
        {
            // Debug
#ifdef DEBUG_USER_BUTTON_PRESS
            if (Raft::isTimeout(millis(), _lastWarnUserShutdownTimeMs, 1000))
            {
                LOG_I(MODULE_PREFIX, "loop button pressed for %dms (vsense %d buttonLevel %d buttonOffTime %dms)",
                    (int)Raft::timeElapsed(millis(), _buttonPressDownTimeMs), vsenseVal, _vsenseButtonLevel, _buttonOffTimeMs);
                _lastWarnUserShutdownTimeMs = millis();
            }
#endif // DEBUG_USER_BUTTON_PRESS

            // Shutdown initiated
#ifdef FEATURE_POWER_CONTROL_USER_SHUTDOWN
            _shutdownInitiated = true;
#endif // FEATURE_POWER_CONTROL_USER_SHUTDOWN
        }
    }
    else
    {
        // Not pressed - debounce
        if (_buttonPressed)
        {
            if (Raft::isTimeout(millis(), _buttonPressChangeTimeMs, 200))
            {
                // Button pressed
#ifdef DEBUG_USER_BUTTON_PRESS
                LOG_I(MODULE_PREFIX, "loop button pressed for %dms and released (button off time %dms)",
                        (int)Raft::timeElapsed(millis(), _buttonPressDownTimeMs), _buttonOffTimeMs);
#endif // DEBUG_USER_BUTTON_PRESS
                _buttonPressed = false;
            }
        }
        else
        {
            // Average vsense values that are not button presses
            _vsenseAvg.sample(vsenseVal);
            _sampleCount++;
        }
    }

    // Debug
#ifdef DEBUG_POWER_CONTROL
    if (Raft::isTimeout(millis(), _lastDebugTimeMs, 1000))
    {
        LOG_I(MODULE_PREFIX, "loop vSense %d avgVSense %d Vcalculated %.2fV battLowThreshold %.2fV sampleCount %d buttonLevel %d",
                    analogRead(_vsensePin), 
                    _vsenseAvg.getAverage(),
                    getVoltageFromADCReading(_vsenseAvg.getAverage()),
                    _batteryLowV,
                    _sampleCount,
                    _vsenseButtonLevel);
        _lastDebugTimeMs = millis();
    }
#endif // DEBUG_POWER_CONTROL

    // Check for shutdown due to battery low
    if (!_shutdownInitiated && (_sampleCount > 100))
    {
        // Get voltage
        float voltage = getVoltageFromADCReading(_vsenseAvg.getAverage());

        // Check for shutdown
        if (voltage < _batteryLowV)
        {
            // Debug
#ifdef DEBUG_POWER_CONTROL
            if (Raft::isTimeout(millis(), _lastWarnBatLowShutdownTimeMs, 1000))
            {
                LOG_I(MODULE_PREFIX, "Battery low %s voltage %.2fV instADC %d avgADC %d battLowThreshold %.2fV", 
#ifdef FEATURE_POWER_CONTROL_LOW_BATTERY_SHUTDOWN
                        "shutting down",
#else
                        "!!! SHUTDOWN DISABLED !!!",
#endif // FEATURE_POWER_CONTROL_LOW_BATTERY_SHUTDOWN
                    voltage, analogRead(_vsensePin), _vsenseAvg.getAverage(), _batteryLowV);
                _lastWarnBatLowShutdownTimeMs = millis();
            }
#endif // DEBUG_POWER_CONTROL

            // Shutdown initiated
#ifdef FEATURE_POWER_CONTROL_LOW_BATTERY_SHUTDOWN
            _shutdownInitiated = true;
#endif // FEATURE_POWER_CONTROL_LOW_BATTERY_SHUTDOWN
        }
    }
}
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

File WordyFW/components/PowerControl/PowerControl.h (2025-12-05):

/////////////////////////////////////////////////////////////////////////////////////////////////////////////////
//
// Power control
//
// Rob Dobson 2023-2025
//
/////////////////////////////////////////////////////////////////////////////////////////////////////////////////

#pragma once

#include <stdint.h>
#include "SimpleMovingAverage.h"
#include "RaftDevice.h"

class RaftJsonIF;

class PowerControl : public RaftDevice
{
public:
    PowerControl(const char* pClassName, const char* pDevConfigJson);
    virtual ~PowerControl() override;

    // Create function
    static RaftDevice* create(const char* pClassName, const char* pDevConfigJson)
    {
        return new PowerControl(pClassName, pDevConfigJson);
    }

    void setup() override final;
    void loop() override final;
    void addRestAPIEndpoints(RestAPIEndpointManager& endpointManager) override final;

    uint32_t getDeviceInfoTimestampMs(bool includeElemOnlineStatusChanges,
        bool includePollDataUpdates) const override final;
    String getStatusJSON() const override final;
    std::vector<uint8_t> getStatusBinary() const override final;
    bool getDeviceTypeRecord(DeviceTypeRecordDynamic& devTypeRec) const override final;

private:

    // Get voltage
    float getVoltageFromADCReading(uint32_t adcReading) const;

    // Check if shutdown initiated
    bool isShutdownRequested()
    {
        return _shutdownInitiated;
    }

    // Handle shutdown
    void shutdown();

    // Apply configuration
    bool applyConfiguration();

    // VSENSE threshold when button is pressed
    static const uint32_t VSENSE_BUTTON_LEVEL_DEFAULT = 2300;
    uint32_t _vsenseButtonLevel = VSENSE_BUTTON_LEVEL_DEFAULT;

    // Configuration applied
    bool _isConfigured = false;

    // VSENSE to voltage conversion for Heart Earrings
    // Note that this is overridden by values in the sysTypes if present
    // Measurements from multimeter
    // 3.584V = 1600
    // 3.697V = 1659
    // 3.804V = 1704
    // 3.899V = 1748
    // 4.003V = 1790
    // 4.107V = 1845
    // 4.203V = 1887
    // Using excel to fit a curve with 0 intercept ...
    static constexpr float VSENSE_SLOPE_DEFAULT = 0.00223;
    static constexpr float VSENSE_INTERCEPT_DEFAULT = 0.0;
    double _vsenseSlope = VSENSE_SLOPE_DEFAULT;
    double _vsenseIntercept = VSENSE_INTERCEPT_DEFAULT;

    // Shutdown due to battery low threshold
    static constexpr float BATTERY_LOW_V_DEFAULT = 3.55;
    float _batteryLowV = BATTERY_LOW_V_DEFAULT;

    // Shutdown initiated
    bool _shutdownInitiated = false;
    
    // Power control pin
    int _powerCtrlPin = -1;

    // Time to hold power control pin low for shutdown
    static constexpr uint32_t TIME_TO_HOLD_POWER_CTRL_PIN_LOW_MS = 500;

    // VSENSE pin
    int _vsensePin = -1;

    // VSENSE averaging
    SimpleMovingAverage<100> _vsenseAvg;
    uint32_t _sampleCount = 0;

    // Debounce button
    bool _buttonPressed = false;
    uint32_t _buttonPressChangeTimeMs = 0;
    uint32_t _buttonPressDownTimeMs = 0;

    // Off time threshold for button press ms
    static constexpr uint32_t BUTTON_OFF_TIME_MS_DEFAULT = 2000;
    uint32_t _buttonOffTimeMs = BUTTON_OFF_TIME_MS_DEFAULT;

    // Debug
    uint32_t _lastDebugTimeMs = 0;
    uint32_t _lastWarnBatLowShutdownTimeMs = 0;
    uint32_t _lastWarnUserShutdownTimeMs = 0;
};

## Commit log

2025-11-05 Added checkbox to fill gaps in grid
    [wordclock-grid.dxf]
2025-11-22 Reorg files
    [FirstAttemptGrid.xlsx, WatchCase.step]
2025-11-23 Updated for real charlieplex array Fixed SysType based on jewelry code Debugging of led charlie panel underway
    [DeviceLEDCharlie.cpp, LEDCharliePanel.cpp, LEDCharliePanel.h]
2025-11-24 Fixed inverted LED polarity
    [LEDCharliePanel.cpp]
2025-11-24 Added debug of timer count
2025-11-25 Word time now showable using API leds/testtime
    Web app has export to header file for C++ import
    LED panel flip option added as the grid is on the reverse of the PCB so numbering is inverted top to bottom
    [Wordy Watch Button with Support.3mf, Wordy Watch Button.3mf, Wordy Watch Case.3mf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]
2025-11-26 Added cutting outline for watch face
    [Cutting Outline.dxf, Wordy Watch Button with Support.3mf, Wordy Watch Button.3mf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]
2025-12-03 Added SVG export to face design
    [LED Diffuser Blocking.3mf, LED Diffuser Pyramids.3mf, wordclock-grid.dxf]
2025-12-05 Firmware updates and case mods
    Added power control
    Added front screen to face
    Added svg export border
    [Front Face.dxf, Wordy Watch Case.3mf]
2025-12-06 Added current time support
    [Wordy Watch Case.3mf]
2025-12-09 Added front chamfer and laser cut file
    [Front Sheet Laser Cut.dxf, Wordy Watch Button with Support.3mf, Wordy Watch Button.3mf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]
2025-12-16 Moved IMU device type to local sysmod
2025-12-16 Fixed problem with power consumption
    Hold enable on charlieplex lines
    [LEDCharliePanel.cpp, WordyWatch.cpp, WordyWatch.h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]
2025-12-16 Added a separate logging channel
    TX only - for use when waking from sleep as the USB JTAG doesn't handle waking up currently
    [WordyWatch.cpp, WordyWatch.h]
2025-12-20 Moved to use basic ESP IDF I2C as polling not needed
2025-12-23 Updated watch case with back plate
    [WatchCase.step, Wordy Watch Case.3mf]
2025-12-24 Increased depth of back plate
    [Wordy Watch Case.3mf, Wordy Watch v19.f3d, Wordy Watch v25.f3d]
2026-01-09 Added Test circuit
2026-01-15 Added calculations spreadsheet
    [20210115 Low Power Calculations.xlsx]
2026-01-15 Added strapping pin and V1.1 systype
    [partitions.csv]
2026-01-15 Renamed systypes to avoid CLI problems
    [partitions.csv]
2026-01-16 Moved all sleep functions to PowerAndSleep class
2026-01-17 Refactored and part working
    RTC working well
    Outputting 32KHz and saving time, etc
    Deep sleep after initial time display
    wake up with any button (inc reset!)
    Simply displays time and goes to sleep again
    80uA in deep sleep with test circuit
    Debug output either to JTAG or UART at the mo - not sure why
    EXT LP clock not detected ... clk: 32 kHz clock not found, switching to internal 150 kHz oscillator
    [20210115 Low Power Calculations.xlsx]
2026-03-31 Made DeviceLEDCharlie more generic
2026-04-01 Added battery gauge Fixed button terminology
    [PowerAndSleep.h, WordyWatch.cpp, WordyWatch.h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]
2026-04-01 Animated power gauge
2026-04-01 Added GRACE lights while battery gauge shown
2026-04-01 Enabled power control
    [20210115 Low Power Calculations.xlsx]
2026-04-02 Show battery level immediately
2026-04-03 Added V1.1 PCB
2026-04-09 Added code to turn off the IMU when asleep Current in deep sleep down to 57uA
2026-04-09 Updated document on power saving
2026-04-09 Removed support for older watch hw
    [partitions.csv]
2026-06-24 Work on watch face
    [FirstAttemptGrid.xlsx, Watch Face Printable.dxf, wordclock-grid.dxf]
2026-06-24 Watch face and PCB attempts
2026-08-21 Face prints added
